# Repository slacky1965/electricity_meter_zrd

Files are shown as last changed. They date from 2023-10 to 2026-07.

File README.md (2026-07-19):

# <a id="Top">Electricity Meter Zigbee TLSR8258</a>

## Устройство для дистанционного мониторинга многотарифных однофазных счетчиков с последующей передачей показаний в Home Assistant.

**Включает в себя схему оптопорта и модуль от Tuya ZTU, который работает, как Zigbee-роутер**

[Repository electricity_meter_zrd](https://github.com/slacky1965/electricity_meter_zrd)

[Версия 1 устройства хранится в отдельной ветке](https://github.com/slacky1965/electricity_meter_zrd/tree/version1) и больше не поддерживается.
[Версия на модуле E180-Z5812SP хранится в отдельной ветке](https://github.com/slacky1965/electricity_meter_zrd/tree/E180-Z5812SP) и больше тоже не поддерживается.

---

* [Описание](#description)
* [Железо](#hardware)
* [Компиляция](#compilation)  
* [Загрузка прошивки](#firmware_download)
* [Принцип работы](#firmware)
* [Настройка](#settings)
* [Приборы учета](#electricity_meters)
* [Home Assistant](#home_assistant)

---

## <a id="description">Описание</a>

* Рассчитано на взаимодействие через оптопорт с однофазными многотарифными электросчетчиками:

	- [Каскад-1МТ](#kaskad-1-mt)
	- [Миртек-12-PY-D1](#kaskad-1-mt) - все тоже самое, что и для Каскад-1МТ
	- [Каскад-11](#kaskad-11) (требует более глубокого тестирования, нет счетчика под рукой)  
	- [Меркурий-206](#mercury-206)
	- [Энергомера-СЕ102М](#energomera-ce102m)
	- [Энергомера-СЕ208BY](#energomera-ce208by)
	- [Нева-МТ124](#neva-mt124)
	- [Нартис-100](#nartis-100)
	- [Нартис-I100](#nartis-100)

* `Electricitymeter` посылает команды электросчетчику и принимает ответы от него. В настоящий момент устройство может прочитать

	- 4 тарифа (в kWh)
	- силу тока (если доступно, в A)
	- напряжение сети (если доступно, в V)
	- мощность (если доступно, в W)
	- оставшийся ресурс батарии прибора (если доступно, в %)
	- полный серийный номер прибора (например 3171112520109)
	- дату изготовления прибора (если доступно, например 04.10.2017)

* Сохраняет в энергонезависимой памяти модуля только конфигурационные данные.
* Передает показания по сети Zigbee.
* Взаимодейстивие с "умными домами" через zigbee2mqtt.
* Первоначальная настройка происходит через web-интерфейс zigbee2mqtt.
* Подключиться к сети или покинуть сеть `Zigbee` - удерживать кнопку более 5 секунд.
* Сделать restart модуля - нажать кнопку 3 раза подряд.
* Однократное короткое нажатие на кнопку - принудительный репорт всех значений.

---

## <a id="hardware">Железо</a>

В проекте используется модуль от компании Tuya на чипе TLSR8258F1KAT32 - ZTU.

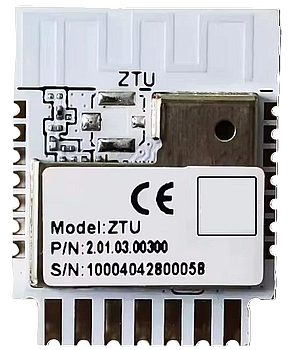
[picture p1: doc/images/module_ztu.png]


Испытывалось все на вот таком dongle от Telink

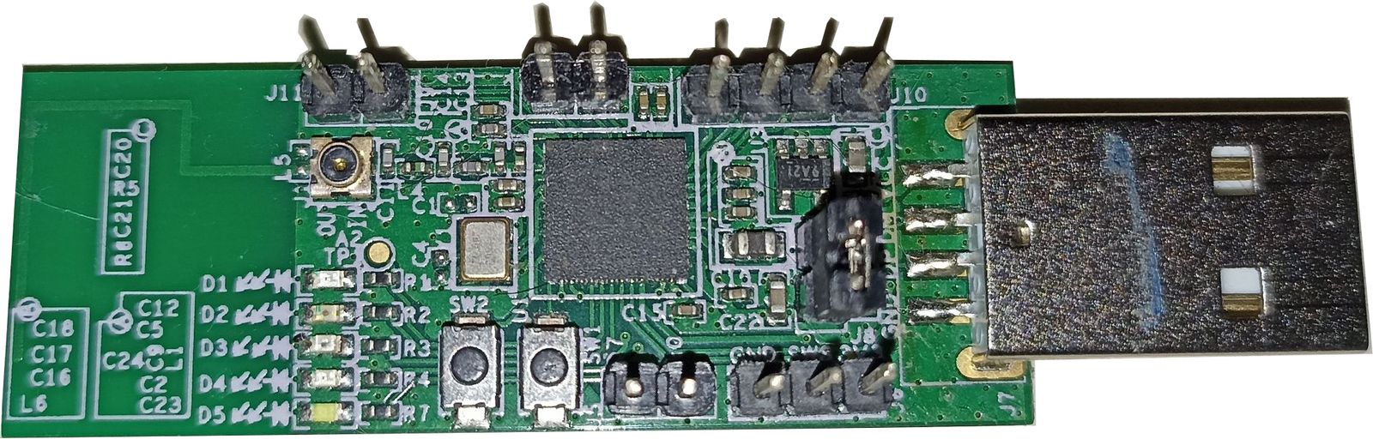
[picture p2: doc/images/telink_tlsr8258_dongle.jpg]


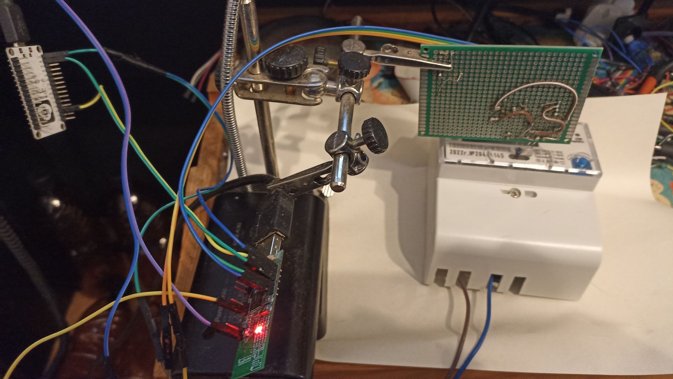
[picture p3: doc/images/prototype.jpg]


**Схема**

Electricity Meter состоит из двух частей. Основной, на которой расположены оптопорт, usb разъем и питание. И модуль zigbee с датчиком температуры. Так сделано для универсальности. К оптопорту можно подключить практически что угодно (модуль на другом чипе, UART-USB преобразователь и т.д.).

<div align="center">
Схема основной части с оптопортом.
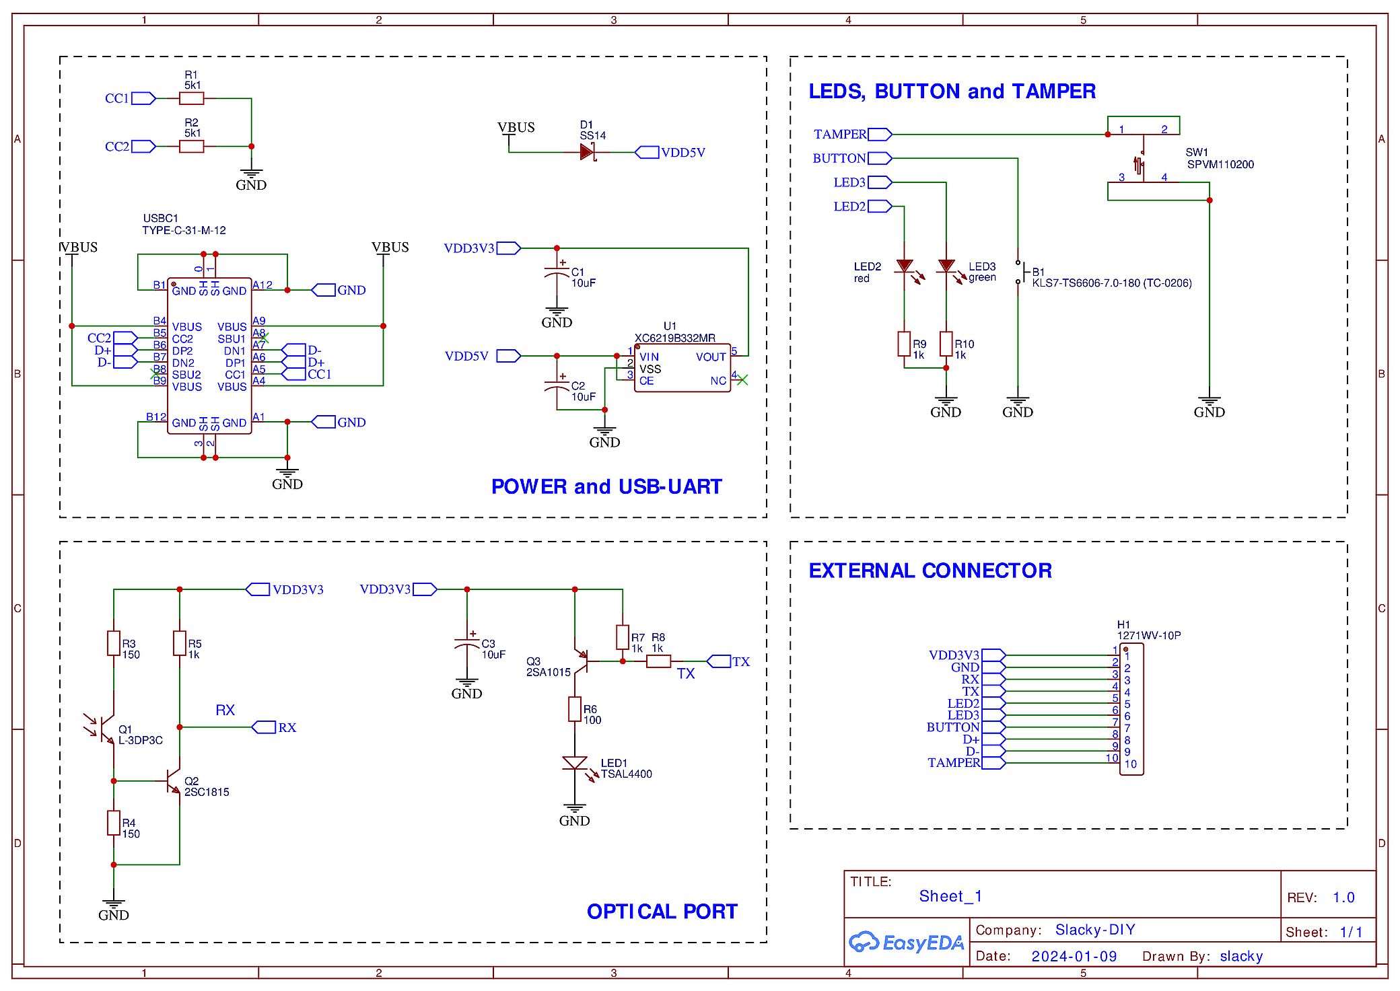
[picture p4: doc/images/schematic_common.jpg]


Схема zigbee на модуле ZTU.
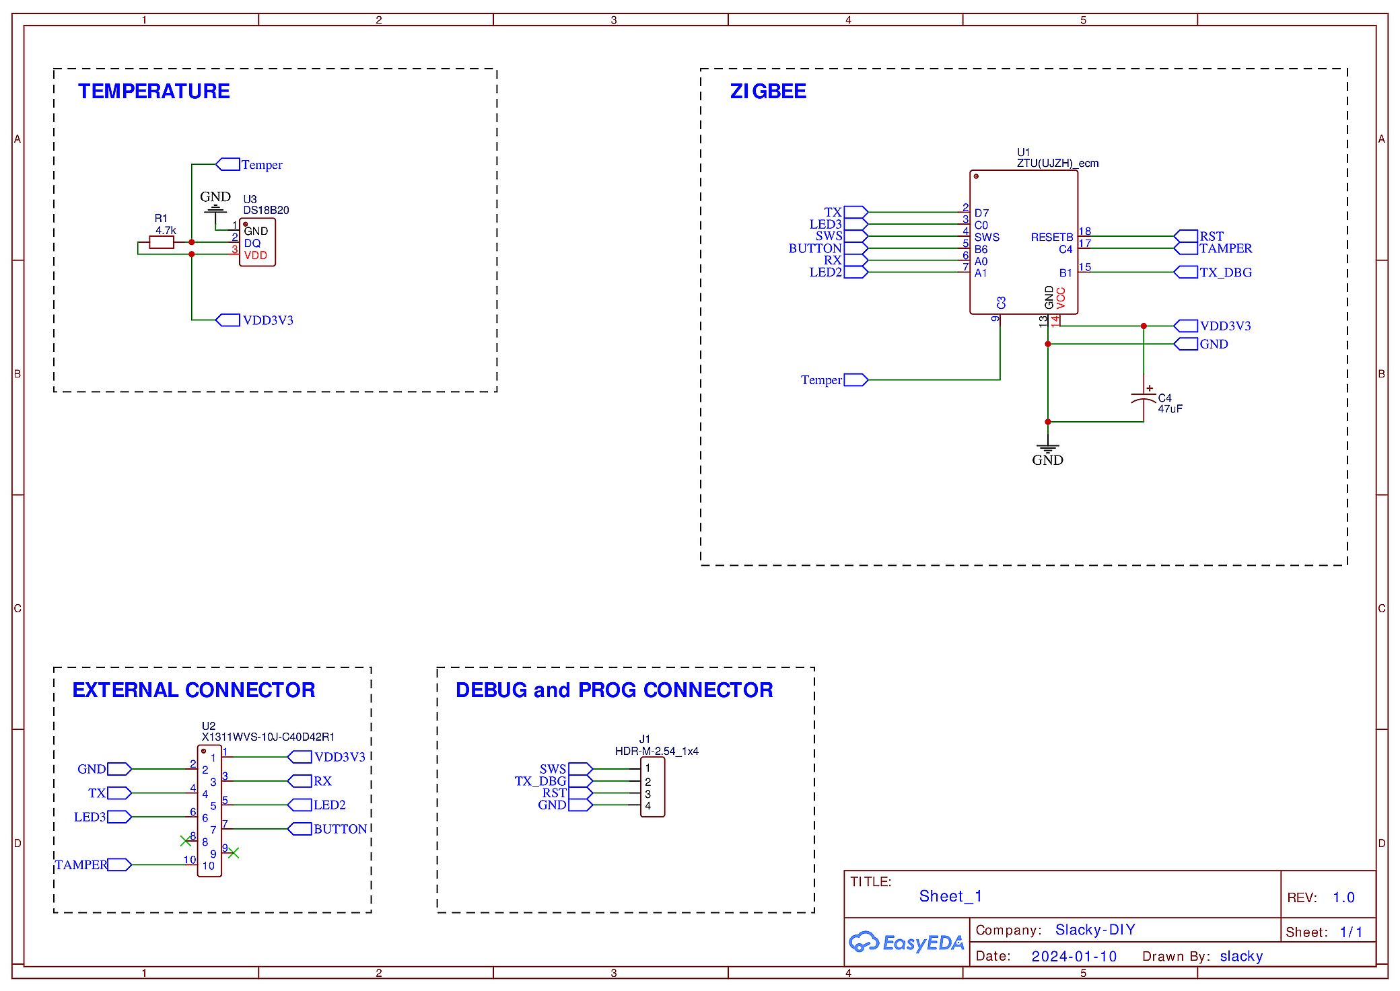
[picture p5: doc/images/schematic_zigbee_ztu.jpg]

</div>

**Плата**

<div align="center">
Плата основной части (верх).

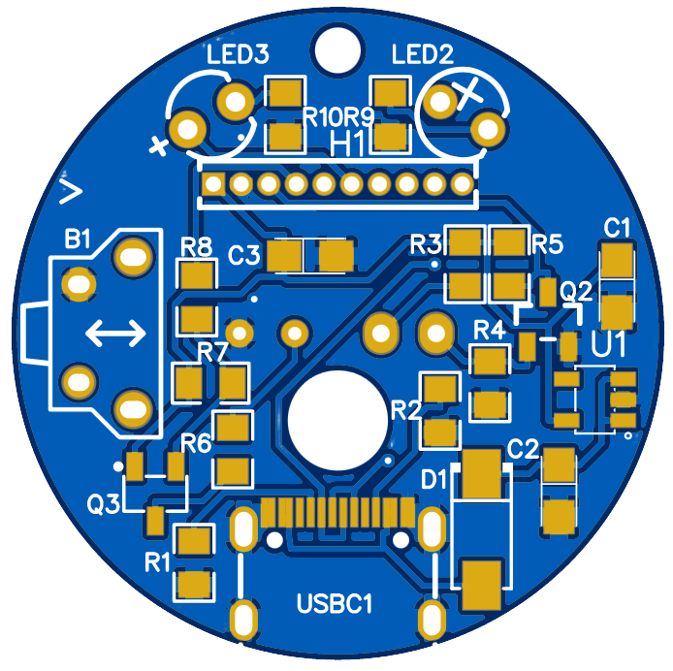
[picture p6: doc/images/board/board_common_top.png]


Плата основной части (низ).

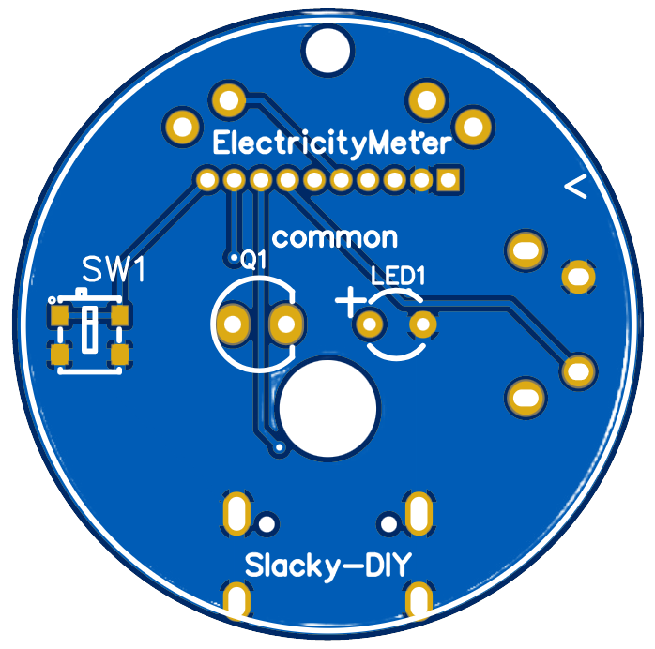
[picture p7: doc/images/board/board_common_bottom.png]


Плата zigbee части на модуле ZTU (верх).

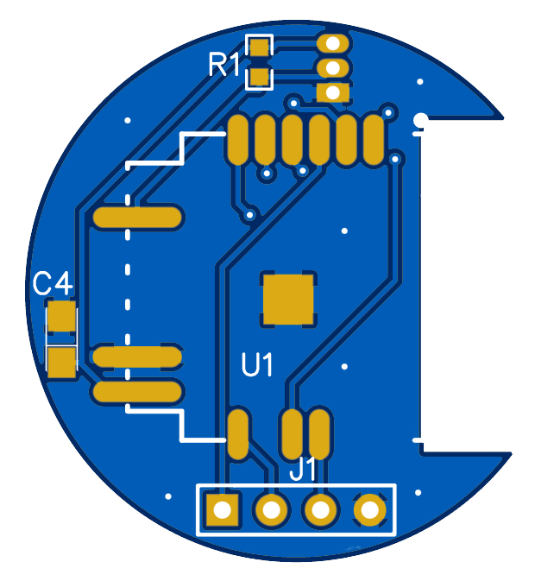
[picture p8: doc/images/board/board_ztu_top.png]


Плата zigbee части на модуле ZTU (низ).

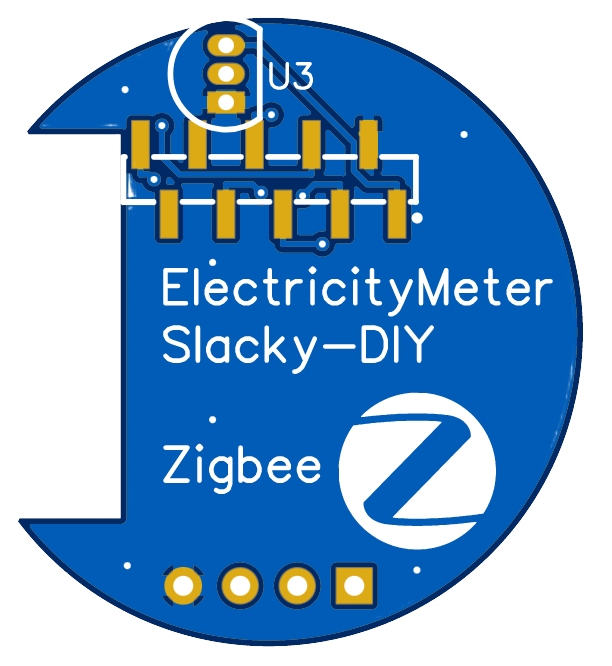
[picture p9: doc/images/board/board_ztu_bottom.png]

</div>

На гребенку выведены следующие пины модуля

* SWS, GND - для заливки в модуль прошивки
* RST, TX-DBG - на всякий случай, вдруг кому-то пригодится.

Ссылки на проект в easyeda

* [Общая часть](https://oshwlab.com/slacky/electricitymeter_zrd_v3_common)
* [Zigbee ZTU]( https://oshwlab.com/slacky/electricitymeter_zrd_v3_ztu)

**Корпус**

Корпус напечатан на 3D принтере.

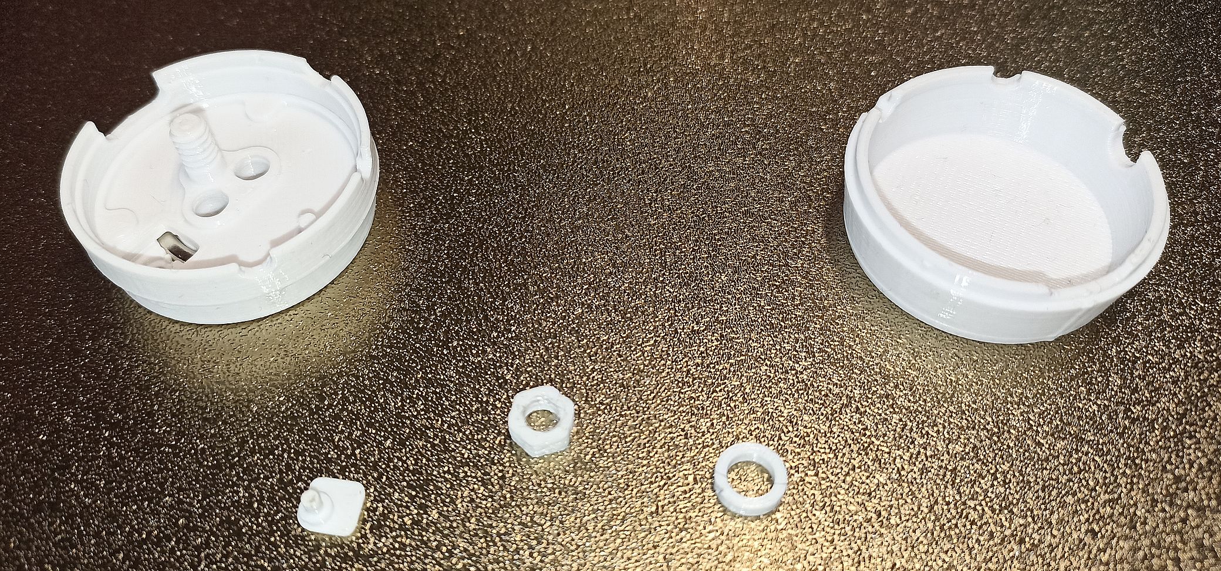
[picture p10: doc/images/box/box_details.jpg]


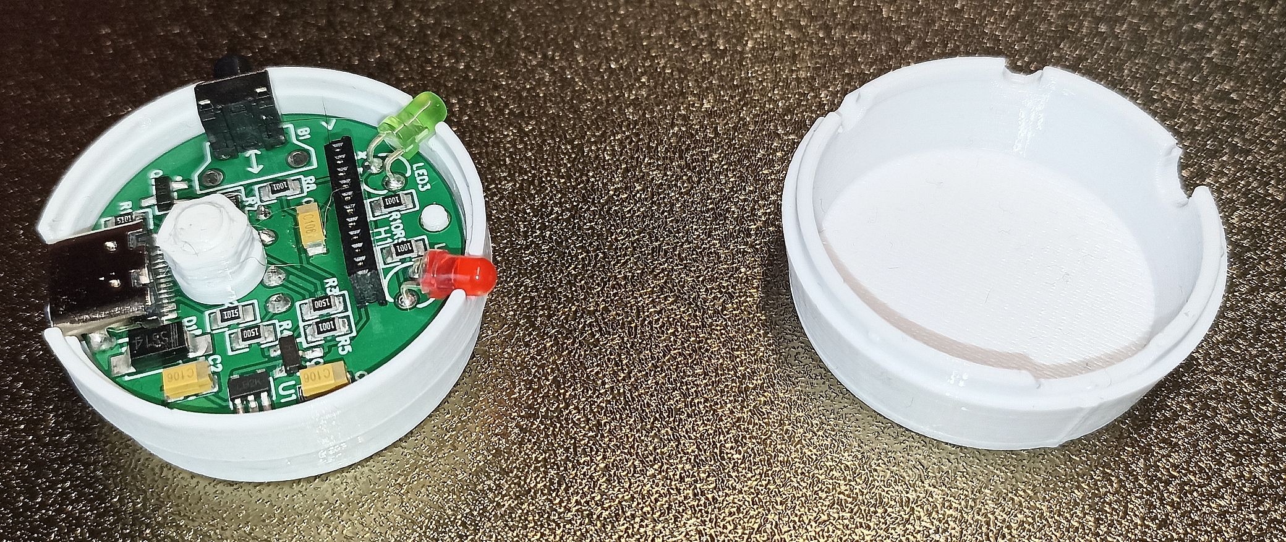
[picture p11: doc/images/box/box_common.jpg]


[STL файл основания](doc/production/ElectricityMeter_Main.STL)

[STL файл крышки](doc/production/ElectricityMeter_Cover.STL)

[STL файл толкателя](doc/production/ElectricityMeter_Pusher.STL)

[STL файл шайбы](doc/production/ElectricityMeter_Spacer.STL)

[STL файл гайки](doc/production/ElectricityMeter_Screw.STL)

**Готовое устройство**

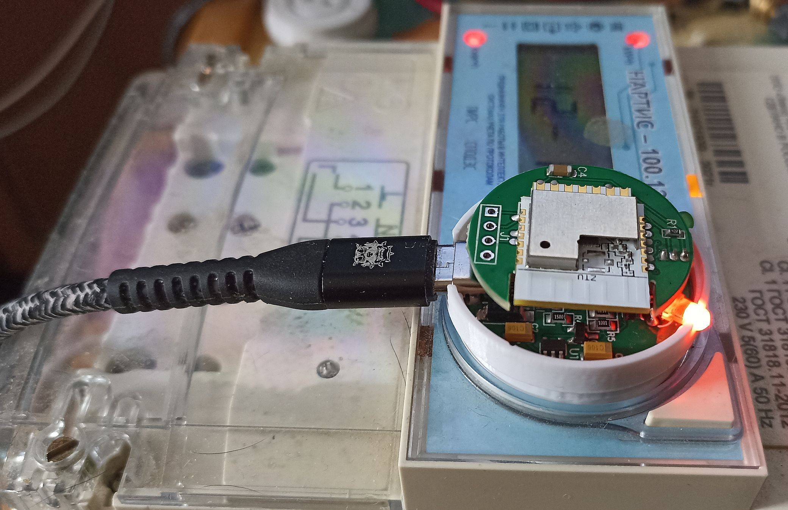
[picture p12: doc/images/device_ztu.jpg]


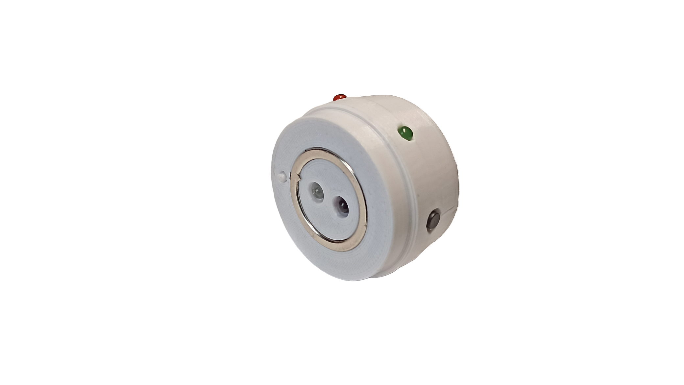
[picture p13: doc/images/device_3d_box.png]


---

## <a id="compilation">Компиляция</a>

[Скачиваем проект](https://github.com/slacky1965/electricity_meter_zrd)  
Если скачали архивом, разворачиваем в какой-нибудь временной директории. Далее запускаем Eclipse. В левом верхнем углу нажимаем File, в развернувшемся меню выбираем Import

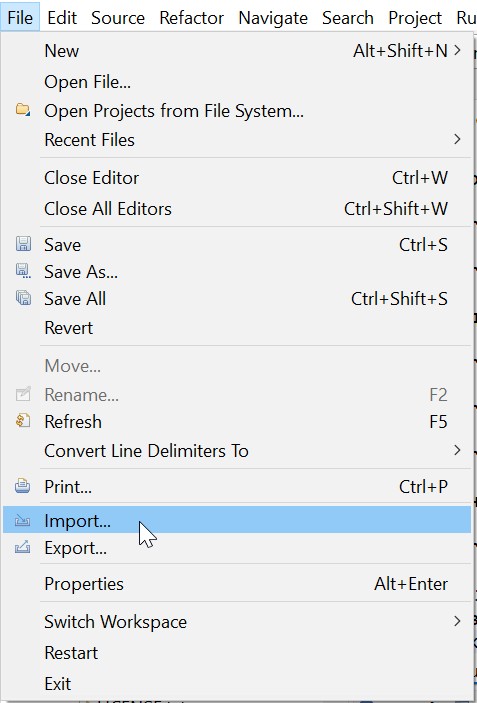
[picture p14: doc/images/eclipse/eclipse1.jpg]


Далее выбираем `Existing Project into Workspace` и жмем `Next`.

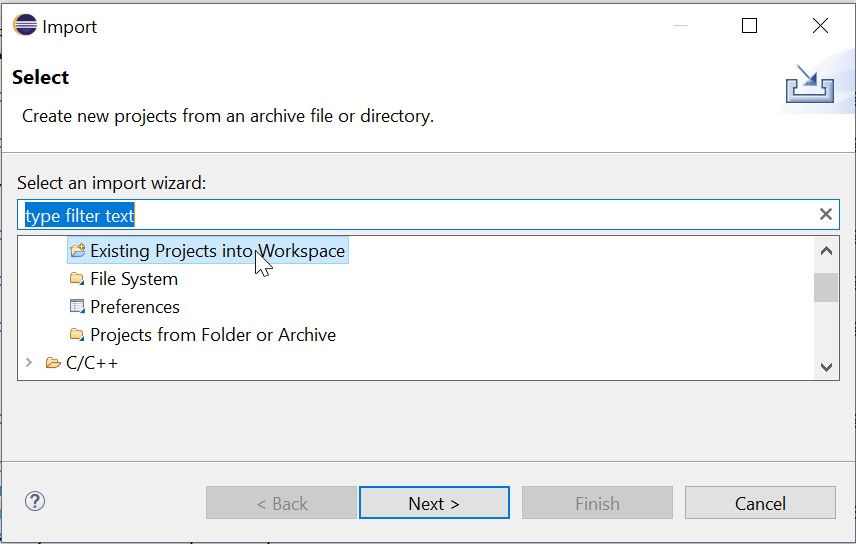
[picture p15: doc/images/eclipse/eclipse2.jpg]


В открывшемся окне по очереди выбираем 

1. `Browse` - находим директорию, куда скачали и развернули проект.
2. Ставим галочку в `Projects:` на появившемся проекте.
3. Ставим галочку на `Copy projects into workspace`
4. Жмем `Finish`

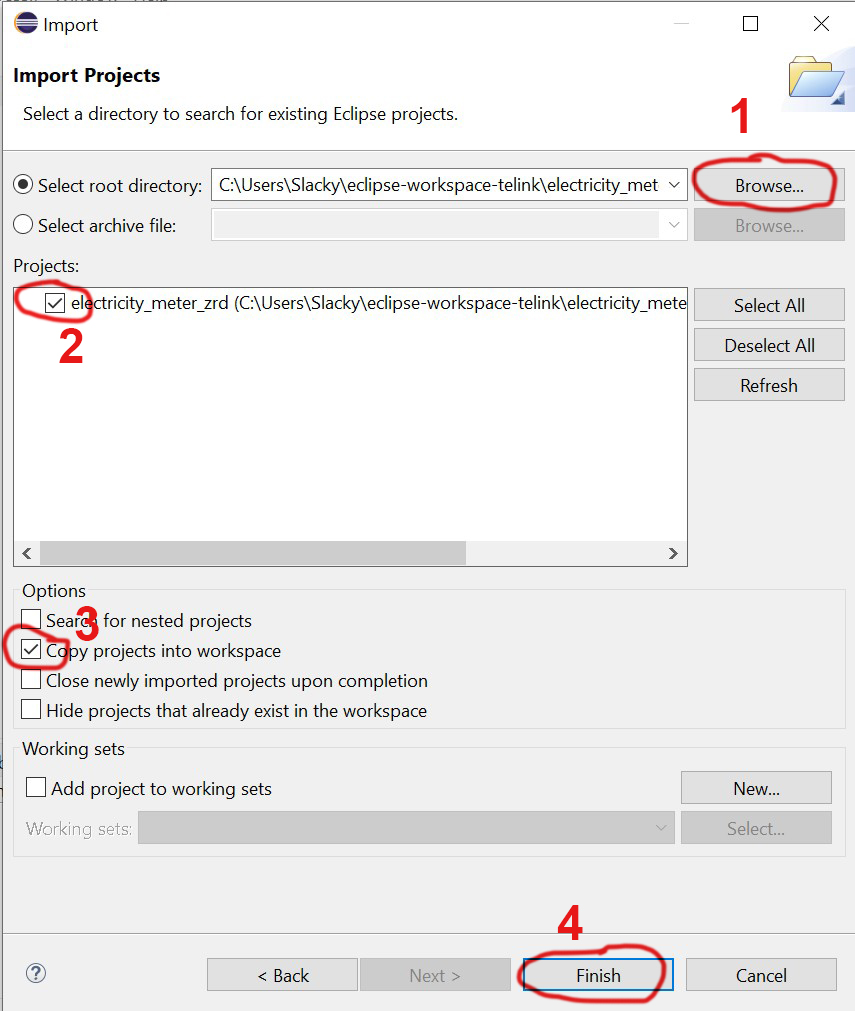
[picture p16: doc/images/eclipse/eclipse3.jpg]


Все, проект у нас в Эклипсе. 

Далее нужен компилятор и кое-какие утилиты. Компилятор можно скачать у [Telink'a](https://wiki.telink-semi.cn/wiki/IDE-and-Tools/IDE-for-TLSR8-Chips/). Установщик поставит IDE (правленый Эклипс) и компилятор с утилитами. Но мне такой винегрет не нравится, поэтому я пользуюсь обычным Эклипсом и makefile. Так же компилятор есть у [Ai-Thinker](https://github.com/Ai-Thinker-Open/Telink_825X_SDK). Там есть под Windows и под Linux. Так же советую скачать [git bash for windows](https://git-scm.com/download/win). Это позволит писать makefiles, которые будут прекрасно работать и под Windows и под Linux практически без редактирования. Еще понадобится Python, но я думаю, это не проблема. Не забудьте отредактировать в makefile и bootloader.makefile пути к компилятору, если он у вас лежит в другом месте.

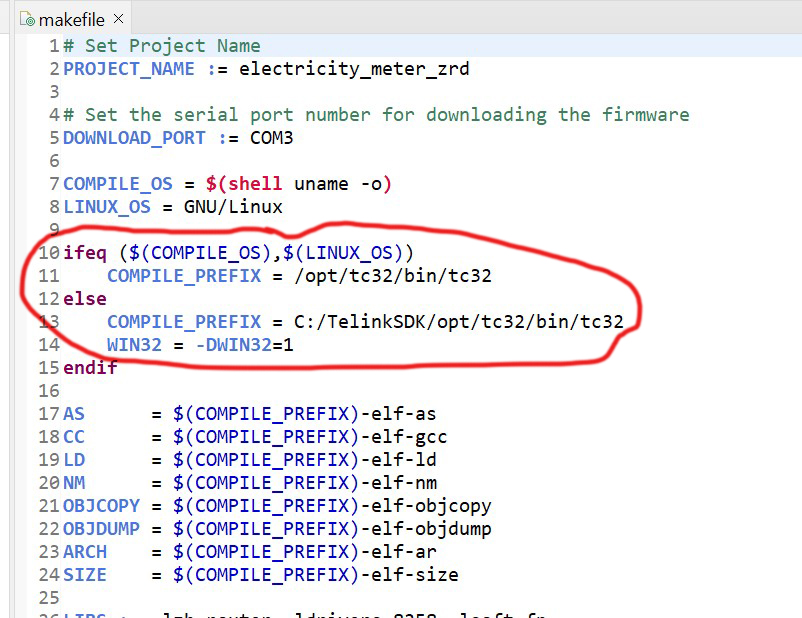
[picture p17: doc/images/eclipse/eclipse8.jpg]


Итак, компиляцию начинаем с `bootloader`. Собираем и прошиваем ([как и чем шить чуть ниже](#firmware_download)). Если модуль пустой, то после прошивки `bootloader'a` модуль просто начнет моргать светодиодом. Это нормально.  

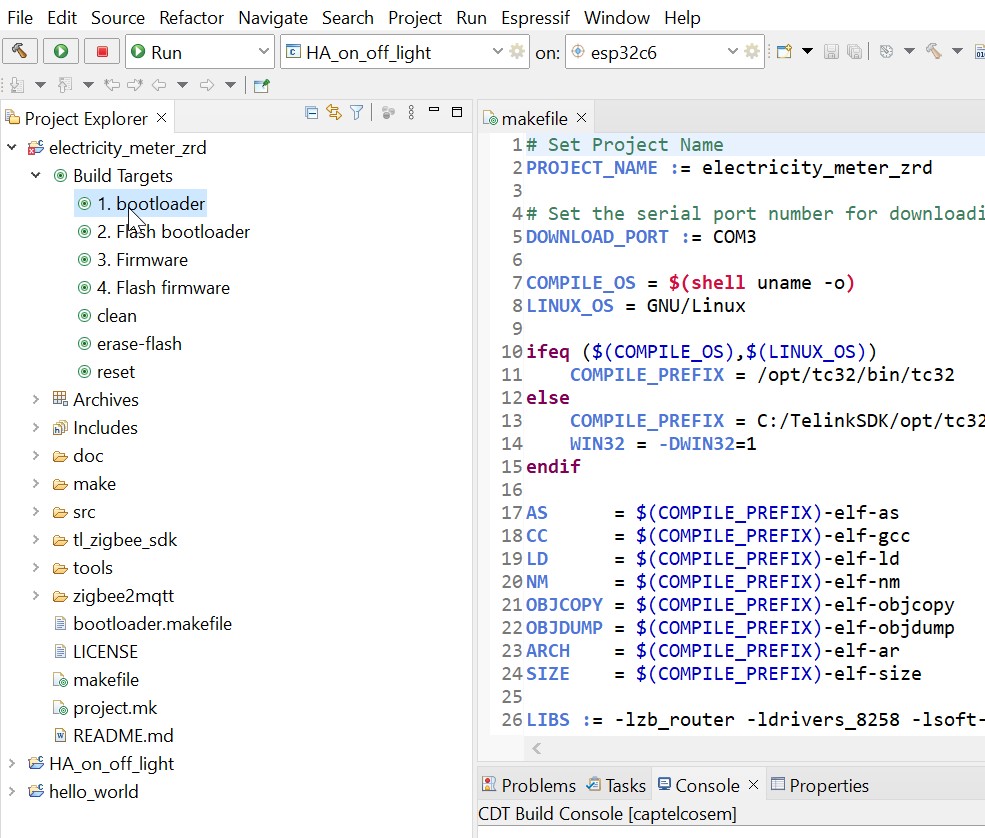
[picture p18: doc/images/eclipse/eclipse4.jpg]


Далее компилируем уже саму прошивку и прошиваем.

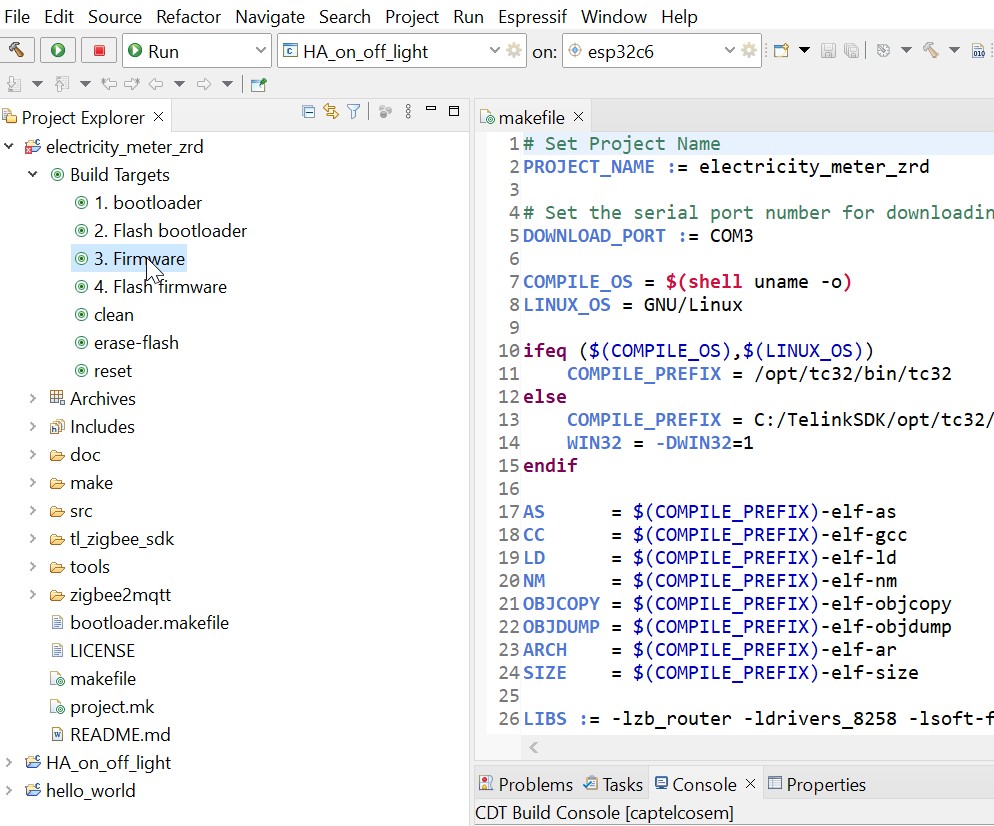
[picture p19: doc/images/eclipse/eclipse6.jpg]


Если все прошло без ошибок, то модуль запустится и начнет работу.

И последнее - проект сделан таким образом, что его можно вообще собрать без IDE, обычнам make в командной строке.

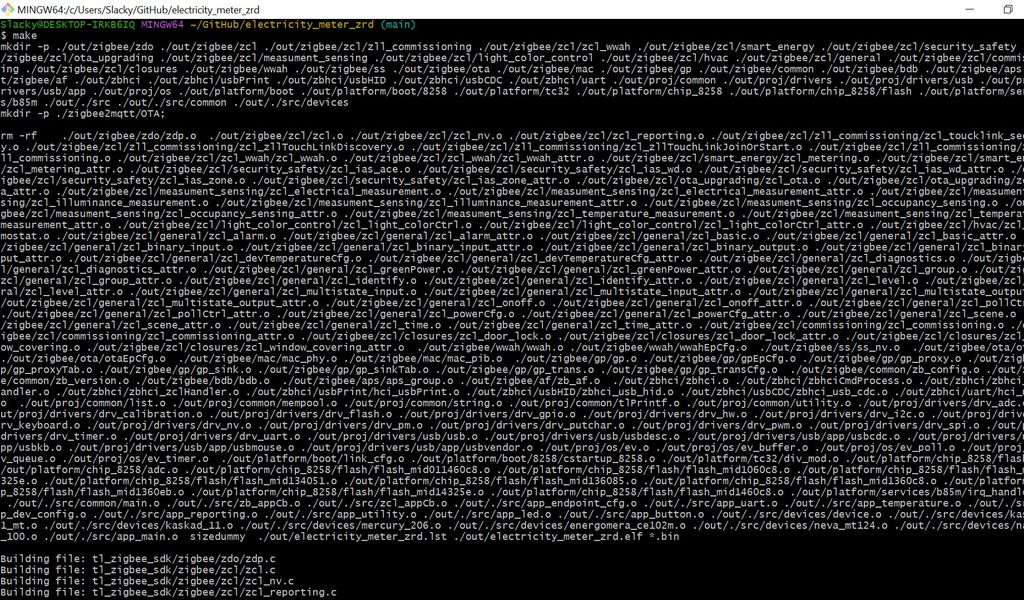
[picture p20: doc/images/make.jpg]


---

## <a id="firmware_download">Загрузка прошивки</a>

Вопрос - как залить прошивку в модуль. Есть несколько вариантов. Самый простой, это приобрести у Telink их фирменный программатор.

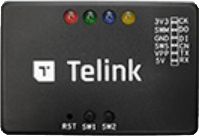
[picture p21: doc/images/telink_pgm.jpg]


Но он неоправдано дорого стоит. Есть другой, более бюджетный вариант. Заказываем модуль TB-04 или [TB-03](http://www.ai-thinker.com/pro_view-89.html) от Ai-Thinker. Почему-то у самого производителя TB-04 не числится. Но на aliexpress их полно. В них применен TLSR8253. Паяем перемычку согласно фото.

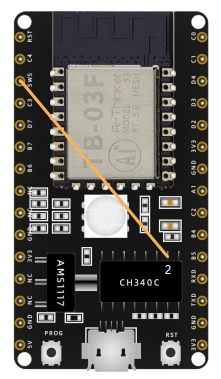
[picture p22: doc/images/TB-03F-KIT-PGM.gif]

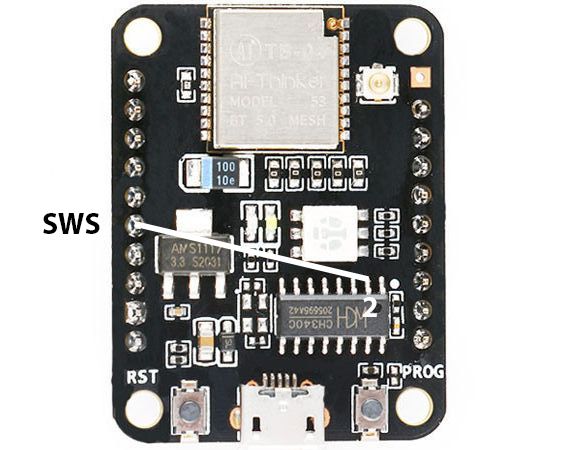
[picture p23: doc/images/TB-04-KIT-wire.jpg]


И заливаем прошивку [вот отсюда](https://github.com/pvvx/TLSRPGM/tree/main/sources/UART2SWire/tb-0x-pgm)

Все, у нас есть недорогой программатор, который может загружать прошивки через SWS в модули от Telink'a. Пин D4 (SWM) программатора нужно соединить с пином SWS программируемого модуля, не забыть объединить земли и подкинуть питание на оба модуля.  
Сама программа-прошивальщик лежит [тут](https://github.com/pvvx/TLSRPGM)

---

## <a id="firmware">Принцип работы</a>

Устройство является роутером, питается от сети ~200 вольт и никогда не спит.  
По умолчанию считывание показаний с электросчетчика происходит один раз в минуту. Изменить в большую сторону можно через интерфейс zigbee2mqtt во вкладке Exposes ([подробней о настройках чуть ниже](#settings)).

**Reporting**

Устройство высылает 13 отчетов.

* Температура (1)
* Четыре тарифа (4)
* Общая энергия по всем тарифам (1)
* Остаточный процент жизни батарейки электросчетчика (1)
* Серийный номер электросчетчика (1)
* Дата изготовления электросчетчика (1)
* Наименование электросчетчика (1)
* Напряжение сети (1)
* Сила тока (1)
* Мощность (1)

Настроить периоды отправки отчетов, если не устроят по умолчанию, можно в интерфейсе zigbee2mqtt во вкладке reporting([подробней о настройках чуть ниже](#settings)).

**Светодиодная индикация режимов модуля**

Красный светодиод сигнализирует о присутствии питания на модуле. Ну и косвенно говорит нам, что программа запустилась и работает. 
Зеленый светодиод служит для информирования о режимах работы модуля.

* Одна вспышка - модуль в сети, считывание данных с электросчетчика успешно.
* Две вспышки - модуль в сети, считывание данных с электросчетчика не происходит.
* Три вспышки - модуль не в сети, считывание данных с электросчетчика успешно.
* Четыре вспышки - модуль не в сети, считывание данных с электросчетчика не происходит.
* Частые постоянный вспышки - модуль пытается подключиться к сети.
	
**Память модуля, прошивка (firmware) и где хранится конфиг**

В версии 3 ОТА реализована, так как модуль ZTU имеет на борту чип TLST8258F1 с 1мБ флеш-памяти. 

Согласно спецификации на чип TLSR8258F1KAT32 при использовании `bootloader'a` память распределена следующим образом

		0x00000  Bootloader
		0x08000  Firmware
		0x77000  OTA Image
		0xE6000  NV
		0xFC000  U_Cfg_Info
		0xFE000  F_Cfg_Info
		0xFF000  MAC address
		0x100000 End Flash

`bootloader` ничего не умеет, кроме, как запускать прошивку с адреса `0x8000` и копировать прошивку из области загрузки в область старта при обновлении через ОТА (при обновлении рекомендуется выбрать счетчик `No Device`).

В конфиге сохраняютстя только настройки модуля. Конфиг записывается в NV (0xE6000) в модуле ZTU. Используется модуль NV_MODULE_APP с номером NV_ITEM_APP_USER_CFG (для понимания смотрите app_cfg.h и tl_zigbee_sdk/proj/drivers/drv_nv.h)

В электросчетчиках используются разные протоколы обмена. Дополнительную информацию смотрите в разделе по конкретному [электросчетчику](#electricity_meters).

---
	
## <a id="settings">Настройка</a>

Первоначальная настройка происходит через web-интерфейс zigbee2mqtt. Для начала нужно убедиться, что устройство в сети. 

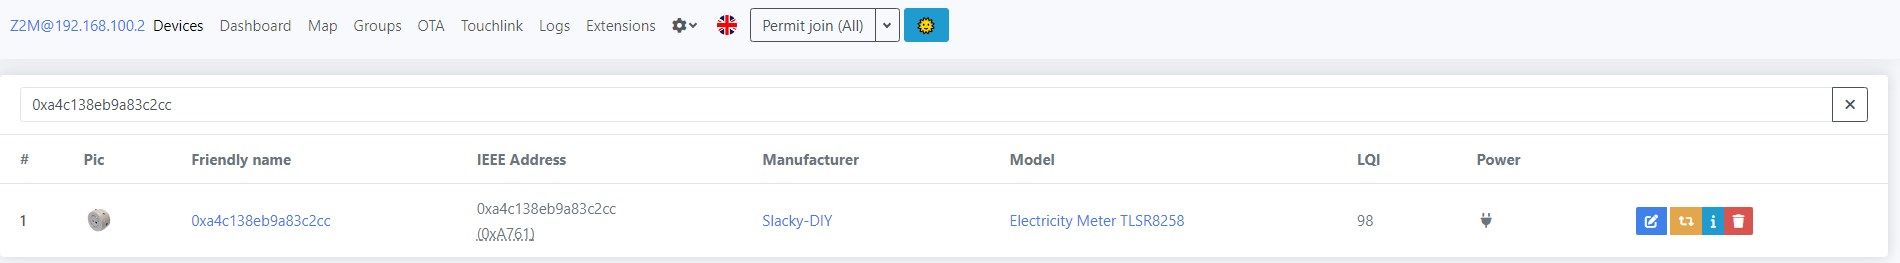
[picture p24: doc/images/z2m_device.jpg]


Если во вкладке `devices` его нет, нужно разрешить сопряжение в `zigbee2mqtt` и если устройство не начало подключаться в течении минуты, зажать кнопку на устройстве на более чем 5 секунд (зеленый светодиод должен начать моргать с частотой примерно раз в секунду). Итак убедились, что устройство в сети, можно переходить к настройкам. Переходим к вкладке `exposes` устройства.

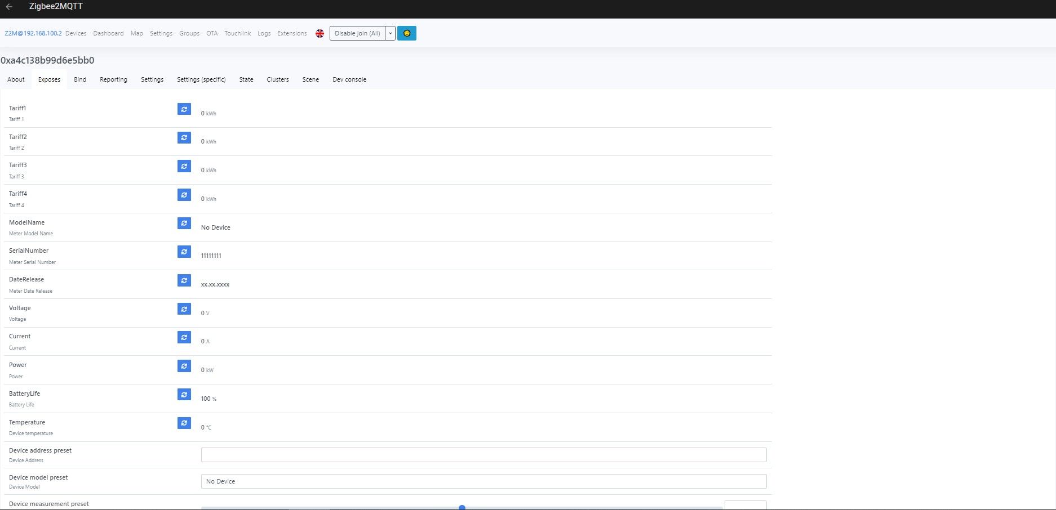
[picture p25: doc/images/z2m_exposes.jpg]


Видим, что в ячейке `Device model preset` выставлен счетчик `No Device`, т.е. никакой счетчик не выбран, считывание данных не происходит. Выбираем нужный счетчик из предложенных. По умолчанию период опроса счетчика - 1 минута. Если нужно больше (максимальное значение 255 минут), меняем настройку `Device measurement preset`.

---

## <a id="electricity_meters">Электросчетчики, поддерживаемые устройством</a>

### <a id="kaskad-1-mt">Однофазный многотарифный счетчик КАСКАД-1-МТ</a>

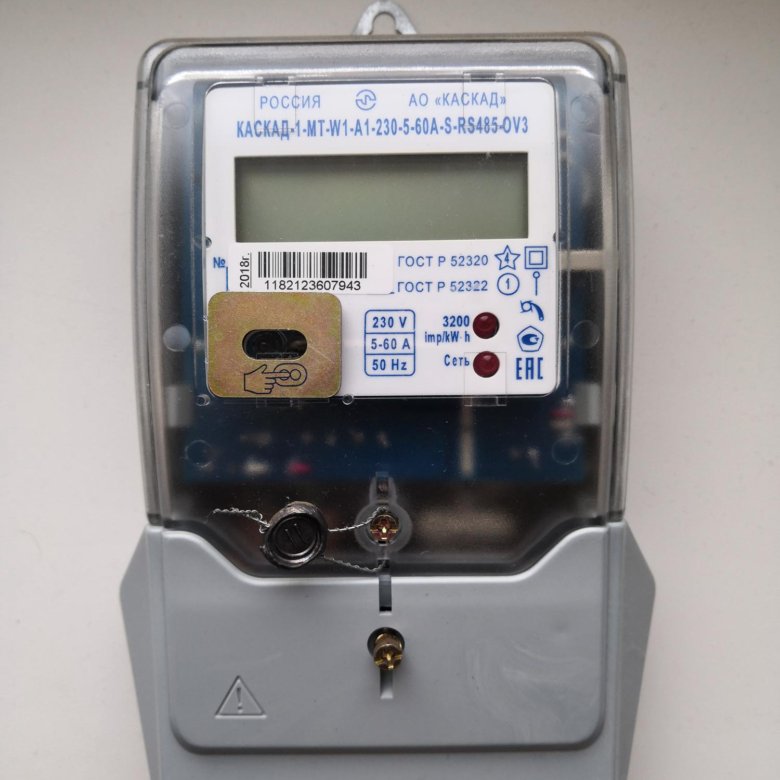
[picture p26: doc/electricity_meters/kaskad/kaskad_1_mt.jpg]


Счетчик общается по протоколу [МИРТЕК](doc/electricity_meters/kaskad/Star_104_304_1.20.doc).

В настоящий момент устройство может прочитать из счетчика:

* 4 тарифа (в kWh)
* силу тока (в A)
* напряжение сети (в V)
* мощность (в kW)
* оставшийся ресурс батареи прибора (в %)
* полный серийный номер прибора (например 3171112520109)
* дату изготовления прибора (например 04.10.2017)

Для корректного соединения со счетчиком в разделе `exposes` в web-интерфейсе `zigbee2mqtt` нужно ввести 5 последних цифр серийного номера прибора. Например для счетчика, который изображен на фото, это 07943. Так, как первая цифра 0, то вводить нужно 7943. Также прибор этот номер показывает на дисплее, как AD-07943.

---

### <a id="kaskad-11">Однофазный многотарифный счетчик КАСКАД-11-C1</a>

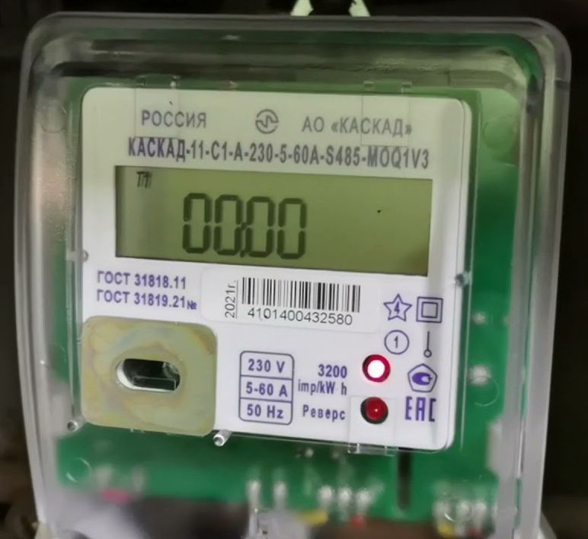
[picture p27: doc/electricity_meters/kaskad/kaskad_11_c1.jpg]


Счетчик общается по своему [протоколу](doc/electricity_meters/kaskad/2023.01.12-KASKAD_11.doc).

В настоящий момент устройство может прочитать из счетчика:

* 4 тарифа (в kWh)
* силу тока (в A)
* напряжение сети (в V)
* мощность (в kW)
* оставшийся ресурс батареи прибора (косвенно вычисляется, команды такой нет, в %)
* полный серийный номер прибора (например 3171112520109)
* дату изготовления прибора (например 04.10.2017)

Для корректного соединения со счетчиком в разделе `exposes` в web-интерфейсе `zigbee2mqtt` нужно ввести 5 последних цифр серийного номера прибора. Например для счетчика, который изображен на фото, это 32580. Также прибор этот номер показывает на дисплее, как AD-32580.

У этого счетчика нет команды запроса ресурса батареи. Поэтому оставшийся ресурс вычисляется из других параметров. Принято считать (во всяком случае разработчики этого счетчика так считают), что ресурс батареи порядка 10 лет. Следовательно, мы просто вычисляем оставшийся ресурс в месяцах между текущей датой прибора, датой производства и 120-тью месяцами (т.е. 10-тью годами). Ну а из этого потом легко получить проценты.

---

### <a id="mercury-206">Однофазный многотарифный счетчик Меркурий-206</a>

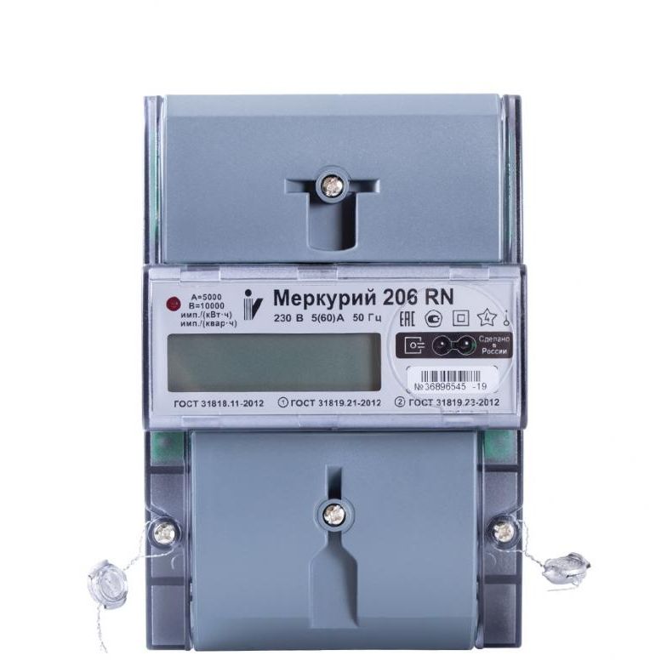
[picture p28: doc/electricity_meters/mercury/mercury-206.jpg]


Счетчик общается по [протоколу](https://www.incotexcom.ru/files/em/docs/mercury-protocol-obmena-1.pdf).

В настоящий момент устройство может прочитать из счетчика:

* 4 тарифа (в kWh)
* силу тока (в A)
* напряжение сети (в V)
* мощность (в kW)
* оставшийся ресурс батареи прибора (косвенно вычисляется, команды такой нет, в %)
* полный серийный номер прибора (например 35900555)
* дату изготовления прибора (например 10.12.2018)

Для корректного соединения со счетчиком в разделе `exposes` в web-интерфейсе `zigbee2mqtt` нужно ввести серийный номера прибора. Например для счетчика, который изображен на фото, это 36896545.

У этого счетчика нет команды запроса ресурса батареи. Поэтому оставшийся ресурс вычисляется из других параметров. Будем считать, что ресурс батареи порядка 10 лет или 120 месяцев. Также есть команда наработки счетчика в часах, отдельно от сети (при наличие входного напряжения 220 вольт) и отдельно от батареи (при отсутствии входного напряжения). Плюсуем эти значения и получаем наработку прибора в часах. А потом мы просто вычисляем оставшийся ресурс в месяцах между 120-тью месяцами (т.е. 10-тью годами) и наработкой. Ну а из этого потом легко получить проценты.

В процессе написания кода для этого счетчика выяснилось, что на первую (любую) команду между опросами, счетчик или не отвечает, или присылает какой-то мусор. А вот на последующие команды отвечает нормально. Поэтому сперва кидаем ему любую команду, делаем небольшую паузу (например 500 мсек) и только потом начинаем опрашивать счетчик.

---

### <a id="energomera-ce102m">Однофазный многотарифный счетчик Энергомера-СЕ102М</a>

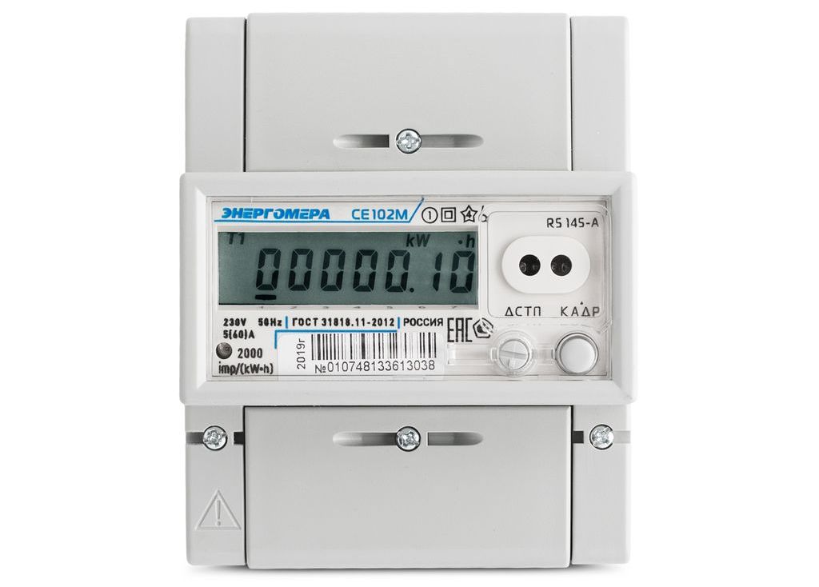
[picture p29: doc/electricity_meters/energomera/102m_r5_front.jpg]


Протокол обмена на этот счетчик размещен на сайте Энергомеры, в [руководстве по эксплуатации](http://www.energomera.ru/documentations/product/ce102m_re.pdf)

В настоящий момент устройство может прочитать из счетчика:

* 4 тарифа (в kWh)
* силу тока (в A)
* напряжение сети (в V)
* мощность (в kW)
* замена батареи (до этого события ресурс будет показан, как 100%).
* полный серийный номер прибора (например 3171112520109)
* дата изготовления прибора у этого счетчика не предусмотрена.

Для этого счетчика серийный номер в web-интерфейсе `zigbee2mqtt` вводить не нужно.

---

### <a id="energomera-ce208by">Однофазный многотарифный счетчик Энергомера-СЕ208BY S53</a>

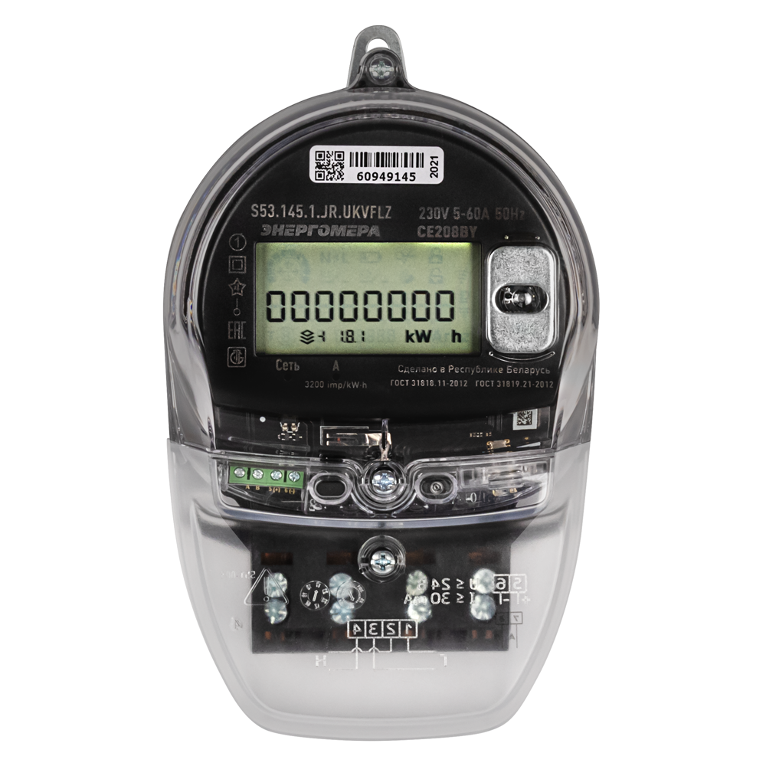
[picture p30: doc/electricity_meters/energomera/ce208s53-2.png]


Протокол обмена на этот счетчик размещен на сайте Энергомеры, в [руководстве по эксплуатации](http://www.energomera.ru/documentations/product/ce102m_re.pdf)

В настоящий момент устройство может прочитать из счетчика:

* 4 тарифа (в kWh)
* силу тока (в A)
* напряжение сети (в V)
* мощность (в kW)
* оставшийся ресурс батареи прибора (вычисляется по напряжению батарейки, команды такой нет, в %)
* полный серийный номер прибора (например 61982867)
* дата изготовления прибора у этого счетчика не предусмотрена.

Для этого счетчика серийный номер в web-интерфейсе `zigbee2mqtt` вводить не нужно.

---

### <a id="neva-mt124">Однофазный многотарифный счетчик Нева-МТ124</a>

В настоящее время устройство поддерживает два счетчика.

**НЕВА МТ 124 AS O 5(60) А**

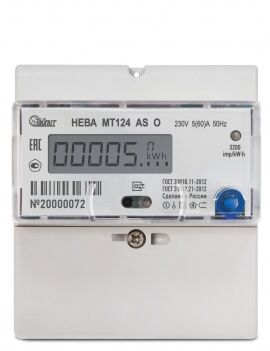
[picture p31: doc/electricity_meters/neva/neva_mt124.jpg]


Протокол обмена описан в `ГОСТ Р МЭК 61107-2001`. В ГОСТе нужно читать только то, что касается режима С. Практически все тоже самое, что в протоколе обмена счетчика `Энергомера-СЕ102М`, за небольшим исключением. Вычисление контрольной суммы отличается от рекомендуемого стандартом и осуществляется как "исключающее ИЛИ". Скорость для начала обмена данными через оптопорт - 300b. После первой команды запроса на соединение, счетчик переходит на скорость 9600b.

В настоящий момент устройство может прочитать из счетчика:

* 4 тарифа (в kWh)
* мощность (в kW)
* оставшийся ресурс батареи прибора (вычисляется по напряжению батарейки, команды такой нет, в %)
* полный серийный номер прибора (например 20404145)
* сила тока (не поддерживается)
* напряжение сети (не поддерживается)
* дата изготовления прибора у этого счетчика не предусмотрена.

**НЕВА МТ 124 AS E4P 5(60) А**

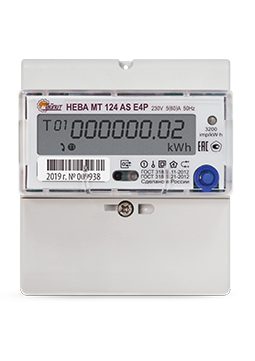
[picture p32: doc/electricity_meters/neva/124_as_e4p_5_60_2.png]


В настоящий момент устройство может прочитать из счетчика:

* 4 тарифа (в kWh)
* силу тока (в A)
* напряжение сети (в V)
* мощность (в kW)
* оставшийся ресурс батареи прибора (не подерживается, всегда 100%)
* полный серийный номер прибора (например 13010971)
* дата изготовления прибора у этого счетчика не предусмотрена.

Для этих счетчиков серийный номер в web-интерфейсе `zigbee2mqtt` вводить не нужно.

---

### <a id="nartis-100">Однофазный многотарифный счетчик Нартис-100 (Нартис-И100)</a>

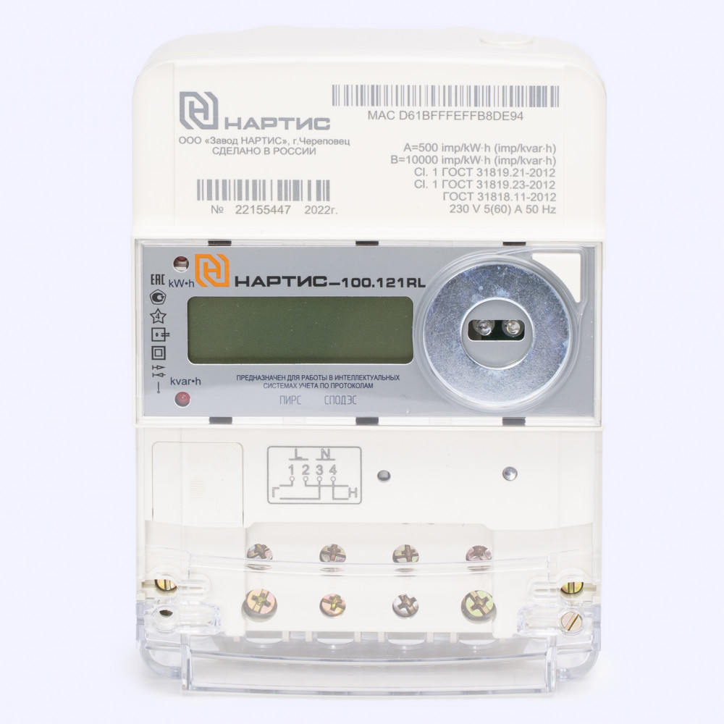
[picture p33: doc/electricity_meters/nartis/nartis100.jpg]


Счетчик общается по протоколу СПОДЭС.

В настоящий момент устройство может прочитать из счетчика:

* 4 тарифа (в kWh)
* силу тока (в A)
* напряжение сети (в V)
* мощность (в kW)
* оставшийся ресурс батареи прибора (косвенно вычисляется, команды такой нет, в %)
* полный серийный номер прибора (например 21021839)
* дату изготовления прибора (например 21.10.2021)

У этого счетчика нет команды запроса ресурса батареи. Поэтому оставшийся ресурс вычисляется между текущей датой прибора, датой производства.

---

Если счетчик выбран и устройство примагничено к окошку оптопорта счетчика, то в `exposes` web-интерфейса `zigbee2mqtt` получим примерно такую картинку.

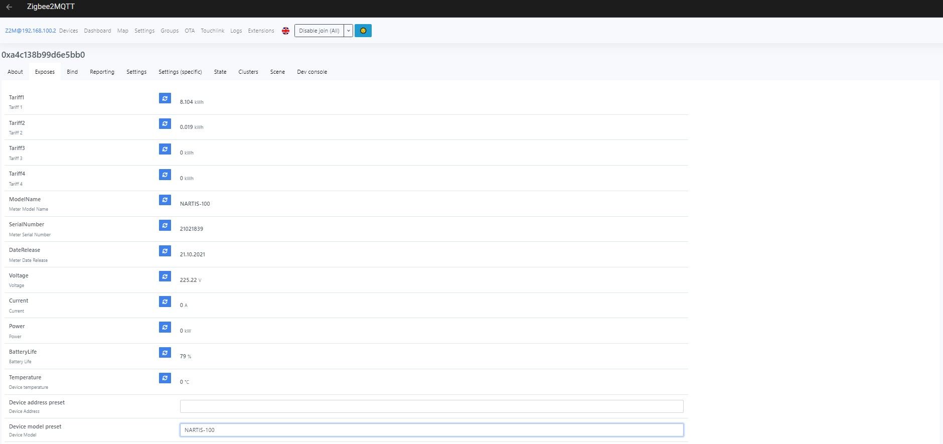
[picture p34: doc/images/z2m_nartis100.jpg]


Если данные не считываются, есть несколько причин.

* Выбран не тот счетчик.
* Не введен адрес счетчика, где он требуется.
* Не совмещены светодиод и фототранзистор на устройстве и счетчике. Рекомендуется немного подвигать устройство.
* Правильное позиционирование Electricity Meter на счетчике - USB разъемом вниз

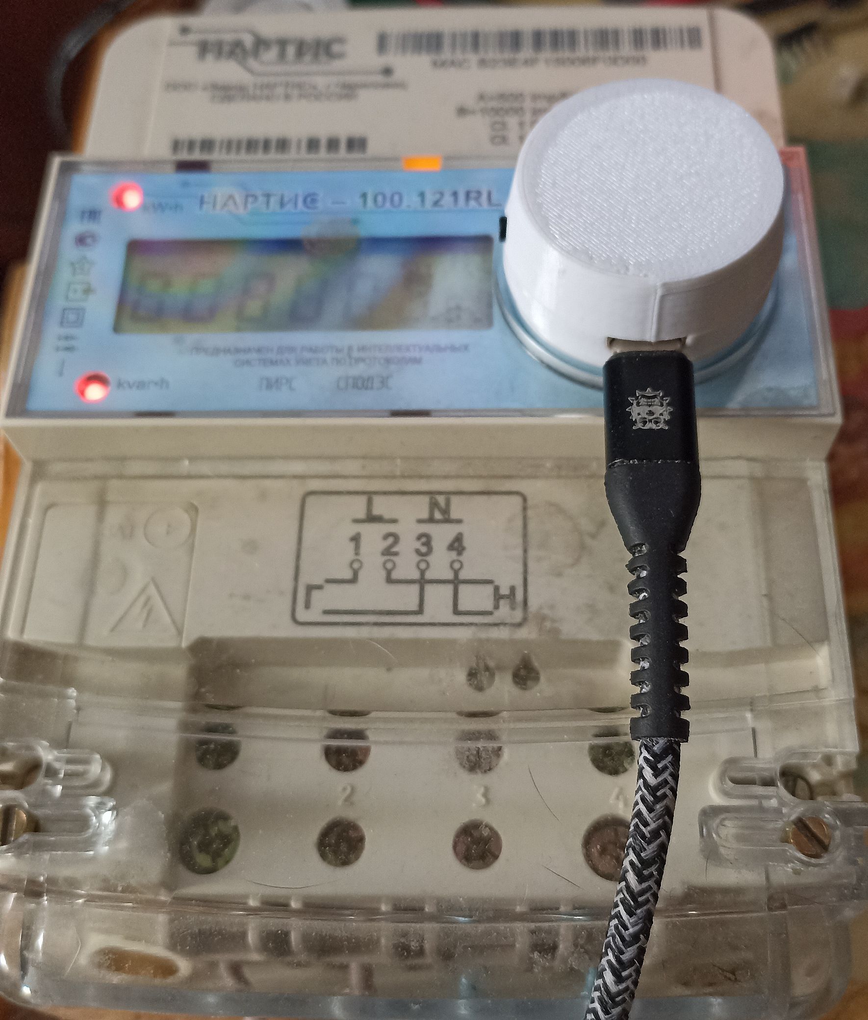
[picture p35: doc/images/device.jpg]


---

## <a id="home_assistant">Home Assistant</a>

В результате вы получите примерно вот такую картинку.

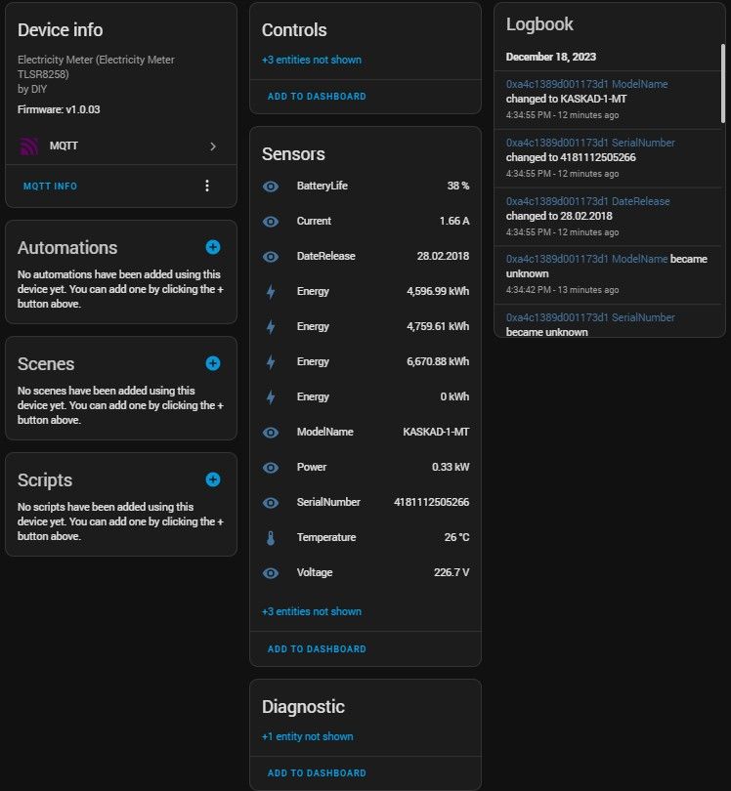
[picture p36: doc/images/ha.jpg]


## История версий
- 1.0.03
	- Добавлен счетчик Нартис-100
	- Отлючена ОТА для увеличения размера прошивки. Загрузка изменена на версию с bootloader'ом.
	- Изменен MANUFACURER_CODE на 0x6565
- 1.0.04
	- Добавлен счетчик Энергомера-СЕ208BY
	- Добавлена другая версия счетчика Нева-124
	- Добавлен сигнал `Tamper` - несанкционированное отсоединение устройства от счетчика.
- 2.0.01
	- Изменены некоторые параметры при считывании счетчика Нартис-100
	- Изменен корпус устройства.
- 2.0.02
	- Добавлена возможность ввода пароля (для счетчиков, где это необходимо)
	- Полностью изменен запрос параметров для счетчика Нартис-100
	- Добавлен счетчик Миртек-12 (выбирать нужно Каскад-1МТ)
- Далее изменения для версии 2 и 3 будут общими.
- x.0.03
	- Добавлен модуль Tuya ZTU для реализации ОТА обновлений.
	- Добавлена дата файла прошивки.
	- Устранен баг с температурой - иногда от датчика приходило некорректное значение температуры, что искажало статистику.
	- Обновлен SDK до версии V3.7.1.2
- x.0.04
	- Изменено имя ZigbeeModel.
	- Изменен атрибут `ZCL_ATTRID_LINE_CURRENT` на 	`ZCL_ATTRID_RMS_CURRENT` и `ZCL_ATTRID_APPARENT_POWER` на `ZCL_ATTRID_ACTIVE_POWER`.
	- Начиная с этой версии не требуется внешний конвертор для `zigbee2mqtt`.
- 3.0.05
	- Отказ от модуля `E180-Z5812SP` в пользу модуля `ZTU`.
	- Добавлен счетчик Нартис-I100.
- 3.0.06
	- Оптимизирована отправка отчетов по нажатию кнопки на устройстве.
	- Убраны принудительные отчеты делителей и множителей.
- 3.0.07
	- Исправлена передача нового пароля.

[Наверх](#Top)

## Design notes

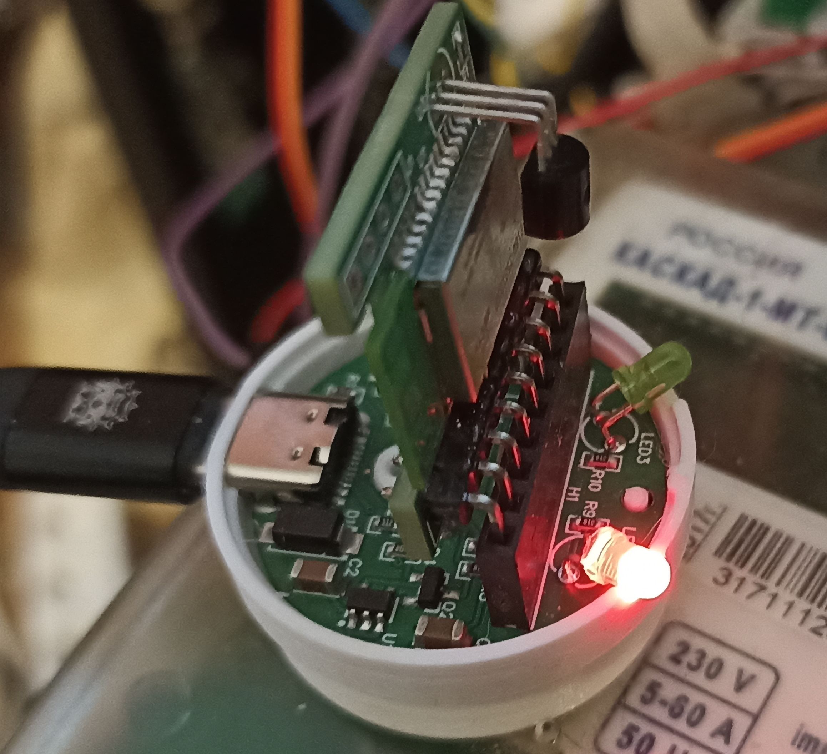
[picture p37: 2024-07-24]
doc/images/device_3d_box.jpg

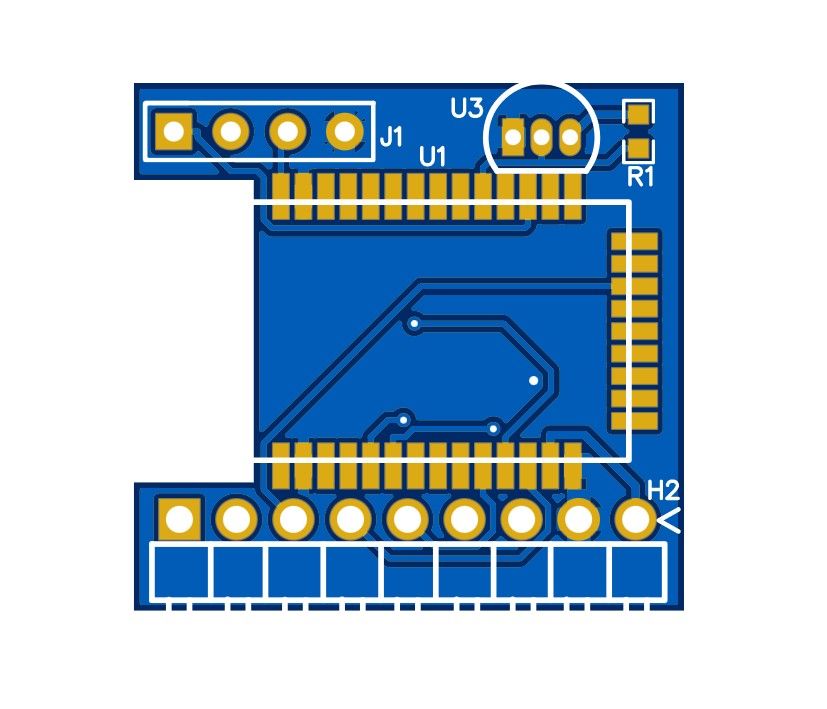
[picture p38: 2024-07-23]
doc/images/board/board_3d_box_zigbee.jpg

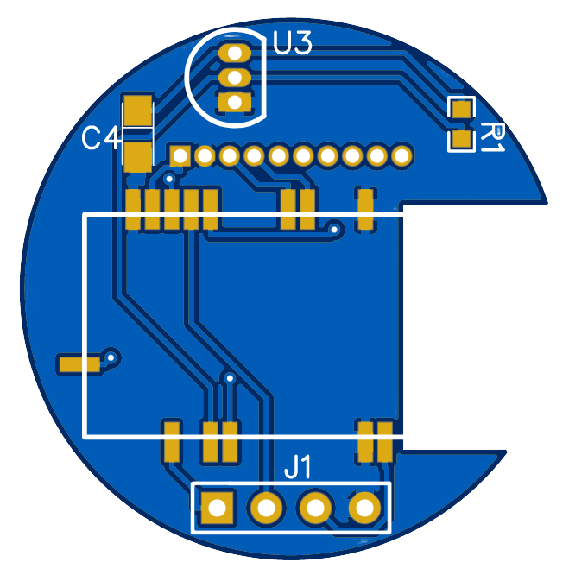
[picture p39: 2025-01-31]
doc/images/board/board_ebyte_top.png

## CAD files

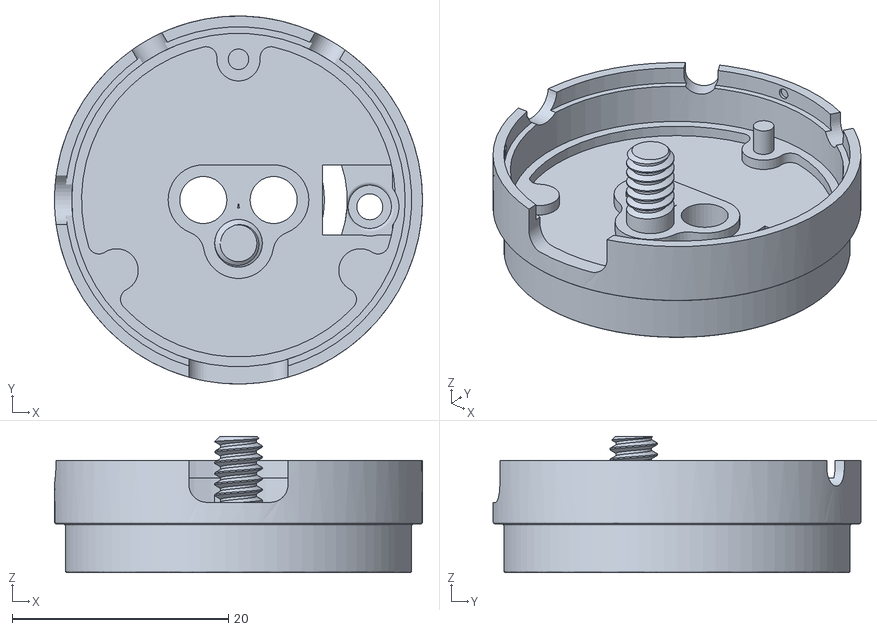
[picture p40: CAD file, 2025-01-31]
doc/production/ElectricityMeter_Main.STL
34.0 x 34.0 x 12.6

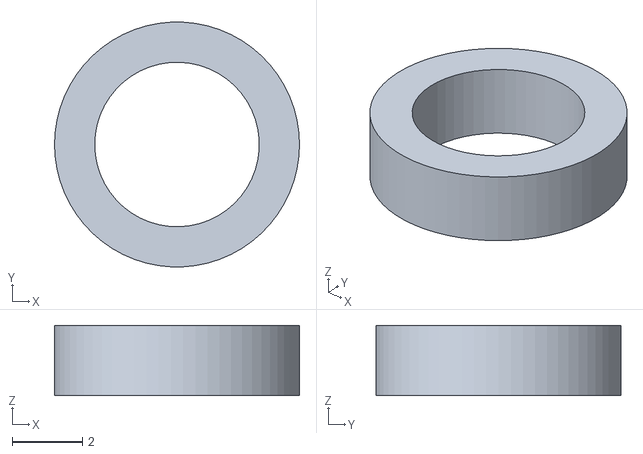
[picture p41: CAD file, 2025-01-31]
doc/production/ElectricityMeter_Spacer.STL
7.00 x 6.99 x 2.00

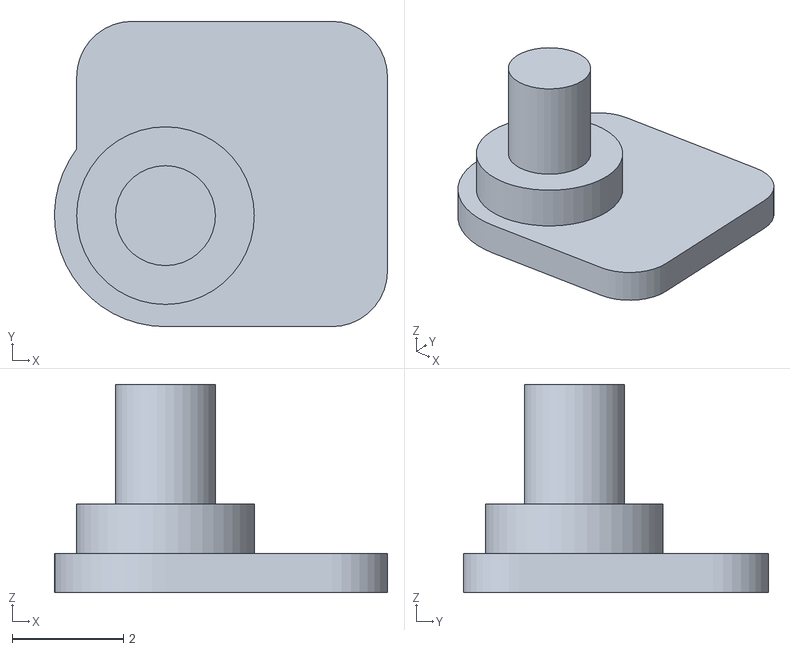
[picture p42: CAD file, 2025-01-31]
doc/production/ElectricityMeter_Pusher.STL
6.00 x 5.50 x 3.75

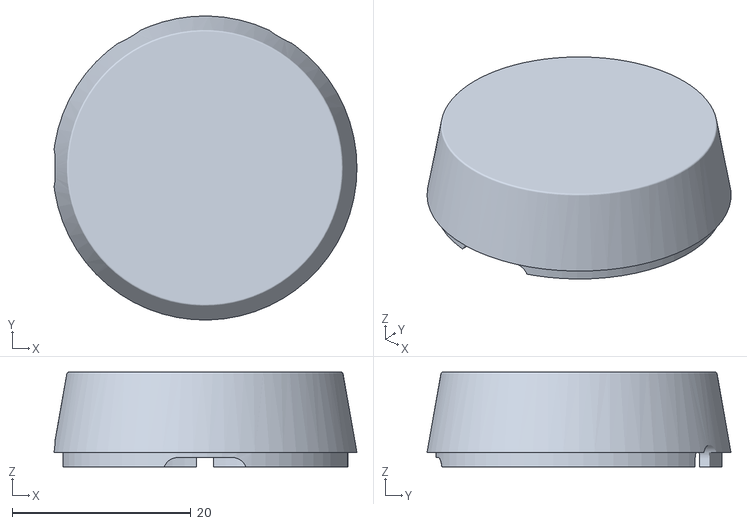
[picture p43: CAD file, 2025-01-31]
doc/production/ElectricityMeter_Cover.STL
33.9 x 34.0 x 10.6

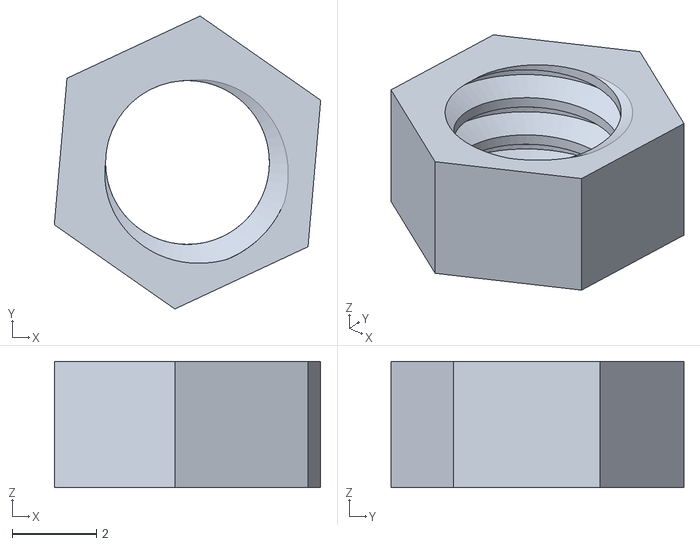
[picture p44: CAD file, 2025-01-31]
doc/production/ElectricityMeter_Screw.STL
6.34 x 6.97 x 3.00

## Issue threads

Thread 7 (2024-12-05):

Готовое устройство

dsm150, 2024-12-05:
Здравствуйте
Возможно ли у Вас приобрести готовое устройство?
Был бы очень признателен за такую возможность 🙏🏻

slacky1965, 2024-12-05:
Здравствуйте.

Напишите мне в телеграмм https://t.me/slacky1965

Closed 2024-12-05.

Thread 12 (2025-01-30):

НАРТИС-И100-W112-2-A1R1-230-5-60А- ST-RS485-RF2400/1-P1-HKLMOQ1V3-D

Sincere74, 2025-01-30:
Доброго дня! Поставили такой счётчик см.ниже, посоветуйте как его добавить в энергомонитор ХА. Пока пойду по инструкции от https://github.com/slacky1965/electricity_meter_zrd#nartis-100 , но уже на этом этапе говорят про "другой пароль". Буду рад любому содействию!

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

НАРТИС-И100-W112-2-A1R1-230-5-60А- ST-RS485-RF2400/1-P1-HKLMOQ1V3-D — это вариант исполнения счётчика электроэнергии однофазного интеллектуального НАРТИС-И100. [1](https://nartis.ru/ru/catalog/pribory-ucheta-elektricheskoj-energii/nartis-i100)[3](https://www.ktopoverit.ru/prof/opisanie/86199-22.pdf)

Характеристики:

Тип корпуса: W112 (для установки на щиток, модификация 2). [3](https://www.ktopoverit.ru/prof/opisanie/86199-22.pdf)
Класс точности: A1R1 (класс точности 1 по ГОСТ 31819.21 и класс точности 1 по ГОСТ 31819.23). [3](https://www.ktopoverit.ru/prof/opisanie/86199-22.pdf)
Номинальное напряжение: 230 В. [3](https://www.ktopoverit.ru/prof/opisanie/86199-22.pdf)
Базовый ток: 5 А. [3](https://www.ktopoverit.ru/prof/opisanie/86199-22.pdf)
Максимальный ток: 60 А. [3](https://www.ktopoverit.ru/prof/opisanie/86199-22.pdf)
Измерительные элементы: ST (шунт в фазной цепи тока и трансформатор тока в цепи тока нейтрали). [3](https://www.ktopoverit.ru/prof/opisanie/86199-22.pdf)
Интерфейсы связи: RS-485. [1](https://nartis.ru/ru/catalog/pribory-ucheta-elektricheskoj-energii/nartis-i100)
Поддерживаемые протоколы передачи данных: СПОДЭС, ПИРС. [1](https://nartis.ru/ru/catalog/pribory-ucheta-elektricheskoj-energii/nartis-i100)[2](https://nectech.pro/products/45-ipue-nartis-i100-w112-na-otecestvennoi-ekb)
Счётчики НАРТИС-И100 могут использоваться автономно, в составе автоматизированных систем контроля и учёта электроэнергии (АСКУЭ), в составе автоматизированных систем диспетчерского управления (АСДУ). [3](https://www.ktopoverit.ru/prof/opisanie/86199-22.pdf)

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

slacky1965, 2025-01-30:
У меня нет такого счетчика, чтобы проверить. Нон я интересовался, там другой адрес и пароль, чем у просто 100. Потому эта программа из коробки с этим счетчиком работать не будет.

latonita, 2025-02-03:
@Sincere74 разные версии имеют разные пароли... 100, 111, 001, 00000001

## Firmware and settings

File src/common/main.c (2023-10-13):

/********************************************************************************************************
 * @file    main.c
 *
 * @brief   This is the source file for main
 *
 * @author  Zigbee Group
 * @date    2021
 *
 * @par     Copyright (c) 2021, Telink Semiconductor (Shanghai) Co., Ltd. ("TELINK")
 *			All rights reserved.
 *
 *          Licensed under the Apache License, Version 2.0 (the "License");
 *          you may not use this file except in compliance with the License.
 *          You may obtain a copy of the License at
 *
 *              http://www.apache.org/licenses/LICENSE-2.0
 *
 *          Unless required by applicable law or agreed to in writing, software
 *          distributed under the License is distributed on an "AS IS" BASIS,
 *          WITHOUT WARRANTIES OR CONDITIONS OF ANY KIND, either express or implied.
 *          See the License for the specific language governing permissions and
 *          limitations under the License.
 *
 *******************************************************************************************************/

#include "zb_common.h"

extern void user_init(bool isRetention);


/*
 * main:
 * */
int main(void){
	startup_state_e state = drv_platform_init();

	uint8_t isRetention = (state == SYSTEM_DEEP_RETENTION) ? 1 : 0;

	os_init(isRetention);

#if 0
	extern void moduleTest_start(void);
	moduleTest_start();
#endif

	user_init(isRetention);

	drv_enable_irq();

#if (MODULE_WATCHDOG_ENABLE)
	drv_wd_setInterval(600);
    drv_wd_start();
#endif

#if VOLTAGE_DETECT_ENABLE
    uint32_t tick = clock_time();
#endif

	while(1){
#if VOLTAGE_DETECT_ENABLE
		if(clock_time_exceed(tick, 200 * 1000)){
			voltage_detect(0);
			tick = clock_time();
		}
#endif

    	ev_main();

#if (MODULE_WATCHDOG_ENABLE)
		drv_wd_clear();
#endif

		tl_zbTaskProcedure();

#if	(MODULE_WATCHDOG_ENABLE)
		drv_wd_clear();
#endif
	}

	return 0;
}

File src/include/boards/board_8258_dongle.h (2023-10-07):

/********************************************************************************************************
 * @file    board_8258_dongle.h
 *
 * @brief   This is the header file for board_8258_dongle
 *
 * @author  Zigbee Group
 * @date    2021
 *
 * @par     Copyright (c) 2021, Telink Semiconductor (Shanghai) Co., Ltd. ("TELINK")
 *			All rights reserved.
 *
 *          Licensed under the Apache License, Version 2.0 (the "License");
 *          you may not use this file except in compliance with the License.
 *          You may obtain a copy of the License at
 *
 *              http://www.apache.org/licenses/LICENSE-2.0
 *
 *          Unless required by applicable law or agreed to in writing, software
 *          distributed under the License is distributed on an "AS IS" BASIS,
 *          WITHOUT WARRANTIES OR CONDITIONS OF ANY KIND, either express or implied.
 *          See the License for the specific language governing permissions and
 *          limitations under the License.
 *
 *******************************************************************************************************/

#pragma once

/* Enable C linkage for C++ Compilers: */
#if defined(__cplusplus)
extern "C" {
#endif


#define DONGLE_8258_32				0
#define	DONGLE_8258_48				1

#if defined DONGLE_8258_32 && (DONGLE_8258_32 == 1)
/*******************************************************************************************************
*********************8258Dongle with 32 Pins: Start*****************************************************
*******************************************************************************************************/
//KEY
#define	BUTTON1 					GPIO_PD7
#define PD7_FUNC					AS_GPIO
#define PD7_OUTPUT_ENABLE			0
#define PD7_INPUT_ENABLE			1
#define	PULL_WAKEUP_SRC_PD7			PM_PIN_PULLUP_10K

#define	BUTTON2 					GPIO_PA1
#define PA1_FUNC					AS_GPIO
#define PA1_OUTPUT_ENABLE			0
#define PA1_INPUT_ENABLE			1
#define	PULL_WAKEUP_SRC_PA1			PM_PIN_PULLUP_10K

//LED
#define LED1						GPIO_PA0
#define PA0_FUNC					AS_GPIO
#define PA0_OUTPUT_ENABLE			1
#define PA0_INPUT_ENABLE			0

#define LED3						GPIO_PD4
#define PD4_FUNC					AS_GPIO
#define PD4_OUTPUT_ENABLE			1
#define PD4_INPUT_ENABLE			0

#define	PM_WAKEUP_LEVEL		  		PM_WAKEUP_LEVEL_LOW

// UART
#if ZBHCI_UART
	#error please configurate uart PIN!!!!!!
#endif

// DEBUG
#if UART_PRINTF_MODE
	#define	DEBUG_INFO_TX_PIN	    GPIO_PC4//print
#endif
/*******************************************************************************************************
*********************8258Dongle with 32 Pins: End*****************************************************
*******************************************************************************************************/
#elif defined DONGLE_8258_48 && (DONGLE_8258_48 == 1)
/*******************************************************************************************************
*********************8258Dongle with 48 Pins: Start*****************************************************
*******************************************************************************************************/

/**************************** Configure UART ***************************************/
#define BAUDRATE_UART           9600
#define GPIO_UART_TX            UART_TX_PD7
#define GPIO_UART_RX            UART_RX_PA0


/************************* Configure Temperature ***********************************/
#define GPIO_TEMP                   GPIO_PC3
#define PC3_FUNC                    AS_GPIO
//#define PC3_OUTPUT_ENABLE           1
//#define PC3_INPUT_ENABLE            1
#define PULL_WAKEUP_SRC_PC3         PM_PIN_PULLUP_1M //PM_PIN_PULLUP_10K

//KEY
#define	BUTTON 					    GPIO_PD6
#define PD6_FUNC					AS_GPIO
#define PD6_OUTPUT_ENABLE			OFF
#define PD6_INPUT_ENABLE			ON
#define	PULL_WAKEUP_SRC_PD6			PM_PIN_PULLUP_1M //PM_PIN_PULLUP_10K

//#define BUTTON  BUTTON1

#define	BUTTON2 					GPIO_PD5
#define PD5_FUNC					AS_GPIO
#define PD5_OUTPUT_ENABLE			0
#define PD5_INPUT_ENABLE			1
#define	PULL_WAKEUP_SRC_PD5			PM_PIN_PULLUP_1M //PM_PIN_PULLUP_10K


//LED
#define LED_STATUS              GPIO_PA2
#define PA2_FUNC				AS_GPIO
#define PA2_OUTPUT_ENABLE		1
#define PA2_INPUT_ENABLE		0


#define LED_POWER               GPIO_PA3
#define PA3_FUNC				AS_GPIO
#define PA3_OUTPUT_ENABLE		1
#define PA3_INPUT_ENABLE		0

//#define LED_POWER                   LED_R
#define LED_PERMIT                  LED_STATUS


//#define	PM_WAKEUP_LEVEL		  	PM_WAKEUP_LEVEL_LOW

// UART
#if ZBHCI_UART
	#error please configurate uart PIN!!!!!!
#endif
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

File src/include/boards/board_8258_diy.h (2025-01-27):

#pragma once

/* Enable C linkage for C++ Compilers: */
#if defined(__cplusplus)
extern "C" {
#endif

/************************* Configure KEY GPIO ***************************************/
#define BUTTON                  GPIO_PB6
#define PB6_INPUT_ENABLE        ON
#define PB6_DATA_OUT            OFF
#define PB6_OUTPUT_ENABLE       OFF
#define PB6_FUNC                AS_GPIO
#define PULL_WAKEUP_SRC_PB6     PM_PIN_PULLUP_1M

/************************* Configure TAMPER GPIO ***************************************/
#define TAMPER                  GPIO_PC4
#define PC4_INPUT_ENABLE        ON
#define PC4_DATA_OUT            OFF
#define PC4_OUTPUT_ENABLE       OFF
#define PC4_FUNC                AS_GPIO
#define PULL_WAKEUP_SRC_PC4     PM_PIN_PULLUP_1M

/**************************** Configure LED ******************************************/

#define LED_STATUS              GPIO_PC0
#define PC0_FUNC                AS_GPIO
#define PC0_OUTPUT_ENABLE       ON
#define PC0_INPUT_ENABLE        OFF

#define LED_POWER               GPIO_PA1
#define PA1_FUNC                AS_GPIO
#define PA1_OUTPUT_ENABLE       ON
#define PA1_INPUT_ENABLE        OFF

#define LED_PERMIT              LED_STATUS


/**************************** Configure UART ***************************************
*    UART_TX_PA2 = GPIO_PA2,
*    UART_TX_PB1 = GPIO_PB1,
*    UART_TX_PC2 = GPIO_PC2,
*    UART_TX_PD0 = GPIO_PD0,
*    UART_TX_PD3 = GPIO_PD3,
*    UART_TX_PD7 = GPIO_PD7,
*    UART_RX_PA0 = GPIO_PA0,
*    UART_RX_PB0 = GPIO_PB0,
*    UART_RX_PB7 = GPIO_PB7,
*    UART_RX_PC3 = GPIO_PC3,
*    UART_RX_PC5 = GPIO_PC5,
*    UART_RX_PD6 = GPIO_PD6,
*/

/**************************** UART for optoport ***********************************/
#define BAUDRATE_UART           9600
#define GPIO_UART_TX            UART_TX_PD7
#define GPIO_UART_RX            UART_RX_PA0

#if UART_PRINTF_MODE
#define DEBUG_INFO_TX_PIN       GPIO_PB1    //printf
#define DEBUG_BAUDRATE          115200
#endif

/************************* Configure Temperature ***********************************/
#define GPIO_TEMP               GPIO_PC3
#define PC3_FUNC                AS_GPIO
//#define PULL_WAKEUP_SRC_PC3     PM_PIN_PULLUP_1M

/* Disable C linkage for C++ Compilers: */
#if defined(__cplusplus)
}
#endif

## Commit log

2023-08-08 added device model
2023-08-20 added devices electricity meter
2023-09-29 test OTA (error. ToDo)
    [zb_appCb.c]
2023-10-05 separate includes path for boards
2023-10-07 battery life reporting added
2023-10-07 Battery Life added
2023-10-07 schematic and board pictures added
2023-10-07 use two boards only (diy and dongle)
2023-10-31 setting common reverse 32() func
    [app_utility.c, mercury_206.c]
2023-11-04 fix reporting when minInterval == 0 and maxInterval == 0
    [app_reporting.c]
2023-11-04 fix printf
2023-11-25 device password added
2025-01-07 fix power divisor for mirtek-12
    [kaskad_1_mt.c]
2025-01-07 fix current from nartis-100
    [nartis_100.c]
2025-01-28 added comments to printf
2025-01-28 fix build 512K and 1M
    [app_cfg.h]
2025-01-28 fix of temperature measurement
    [app_temperature.c]
2025-01-29 debug temperature off
2025-01-31 added new STL files for 3D printing
    [ElectricityMeter_Cover.STL, ElectricityMeter_Cover_New.STL, ElectricityMeter_Main.STL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]
2025-01-31 added new gerber files
2025-01-31 added new pictures of device
2025-01-31 added new schematics
